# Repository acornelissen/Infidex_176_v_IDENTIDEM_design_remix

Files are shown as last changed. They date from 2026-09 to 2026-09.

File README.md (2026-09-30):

# Infidex 176 V x IDENTIDEM.design Remix

> **This is a remix of someone else's design.** The Infidex 176 V is an open source 3D-printed panoramic 35mm camera by **Denis Aminev (Time to Waste)**. Everything here builds on his work.
>
> - Original project: **[Infidex 176 V on GitHub](https://github.com/max05210238/Infidex_176_V)**
> - Original designer: **[Denis Aminev — Time to Waste on YouTube](https://www.youtube.com/@time_to_waste)**
> - This remix: **[IDENTIDEM.design](https://IDENTIDEM.design)**
>
> Print the original first if you want the camera as Denis designed it. Attribution stays with him; please keep it with any further remix.

## What this remix is

The camera is unchanged where it counts: same 3:1 panoramic frame on 35mm film, same Mamiya TLR taking lens, same overall shape. What changed is how it goes together and how you know where you are on the roll.

| | Original | This remix |
|---|---|---|
| Body | One piece | Reworked, and supplied two ways: in one piece, or as two halves glued together with a light-tight lip and alignment pegs |
| Frame counting | Count as you wind | Sprocket-driven gear train and a numbered counter face, starting at 25 |
| Counter dial | None | Two versions: a free-running dial, or one held by a ball plunger for a steadier reading |
| Rewind knob | Spring detent | Three ball plungers |
| Take-up coupling | Dog coupling | Inner-ratchet with three ball plungers for wind and rewind, magnets optional |
| Spool retention | Glued washer | Printed split collar (`takeup-washer-stopper`) that clicks into the groove |
| Pressure plate | Foam | Printed leaf-spring platen, bonded to the door at both ends |
| Fixings | Glue and press fits | Heat-set inserts and screws throughout |
| Viewfinder | Separate | Cold-shoe viewfinder coupled to the focus helicoid |

## Focusing scale generator

**[infidex176v-focus-scale.identidem.design](https://infidex176v-focus-scale.identidem.design/)** makes a focusing scale for your own lens. Give it the focal length, the helicoid thread lead and your focus ring diameter, and it returns the scale as SVG or Gerber, marked from infinity down to 1.44 m, ready to print as a decal or etch as a plate.

## Specifications

Carried over from the original design:

- **Format:** 3:1 panoramic, 72 × 24 mm on 35mm (135) film
- **Frames:** 18 per 36-exposure roll, or 19 if you load in darkness
- **Lens:** Mamiya TLR taking lens, 80mm or 55mm, from the C2/22/220 or C3/33/330 series
- **Body:** about 168 × 67 × 38 mm
- **Filament:** under 600 g for a camera
- **Tripod mount:** 3/8"-16 thread printed straight into the base, five turns and 8.5 mm deep. Most tripods and quick-release plates are 1/4"-20, so fit a 3/8" to 1/4" bushing and leave it in. Start it by hand: a printed thread strips if you drive it with a tool.

Specific to this remix:

- **Frame counter:** 50:1 spur train, module 0.6, four meshes (12:32, 12:30, 12:30, 12:36), one counter-face turn per 25 frames
- **Counter face:** starts at 25 as the loading position, then reads 1, 2, 3 and on as you wind; friction-fitted under a thumbscrew, reset by loosening it and turning 25 back to the marker
- **Counter dial:** simple (free-running) or drag (one extra ball plunger presses on the dial rim), see [Counter dial: simple or drag](#counter-dial-simple-or-drag)

## Files

| File | What it is |
|---|---|
| `cad/Infidex176V-IDENTIDEM.design-remix.step` | Full assembly, STEP, for any CAD package |
| `cad/Infidex176V-IDENTIDEM.design-remix.f3d` | Fusion source for the camera |
| `cad/Infidex176V-IDENTIDEM.design-remix-counter-train.f3d` | Fusion source for the parametric counter gear train |
| `3mf/Infidex176V-IDENTIDEM.design-remix.3mf` | Print-ready project, all parts laid out across nine plates |
| `3mf/parts/` | One 3MF per part, for reprinting a single part |
| `Infidex-Hardware-Map.pdf` | Hardware placement and assembly guide, 7 pages, built from `docs/hardware-map/` |
| `tools/InfidexCounterTrain/` | Fusion script that rebuilds the counter train from parameters, see [`tools/README.md`](tools/README.md) |
| `flocking/` | Full-size flocking templates, PDF and DXF |
| `docs/` | Section drawings used in this README, and the source of the hardware guide |
| `NOTICE.md` | Denis's redistribution notice, and the remix notice |
| `CHANGELOG.md` | Releases, the commits behind them and which parts to reprint |

## Printing

Print settings follow the original profile and work well in PETG:

- 0.4 mm nozzle, 0.2 mm layer height
- 4 perimeters, up to 25% infill
- Denis printed the original in ABS. PETG works well and is easier to live with
- Both halves of the two-piece body sit flat on their seam face, which puts the largest surface on the bed. Add supports wherever your slicer flags overhangs
- The one-piece body prints as in the original if you would rather not glue

The counter train gears are the finest parts in the model. Print them with the rest of the camera, check the teeth before assembly, and reprint if a tooth is short.

### Parts

Print the whole camera from the project file in `3mf/`, which has everything arranged across 14 plates with the per-part settings already set. `3mf/parts/` holds the same 34 parts one to a file, plus a two-colour version of each counter face and each knob, each in the orientation it is meant to print in and sitting on the bed, for when you only need to reprint one. Updating an earlier build? [`CHANGELOG.md`](CHANGELOG.md) lists the parts to reprint for each release.

Some parts are a choice rather than a set. Print one from each of these:

- **Body:** `body-solid`, or `body-top` and `body-bottom` together
- **Door:** `door-var-1` to `door-var-4`
- **Viewfinder:** `viewfinder-var-1` or `viewfinder-var-2`
- **Focus ring:** `helicoid-focus-ring-ribs` or `helicoid-focus-ring-no-ribs`
- **Helicoid inner ring:** `helicoid-inner-ring-for-80mm-lens` or `helicoid-inner-ring-for-55mm-lens`, to suit your taking lens
- **Counter dial:** `simple-cover` with `simple-counter-face`, or `drag-cover` with `drag-counter-face`. Print them as a matched pair; see [Counter dial: simple or drag](#counter-dial-simple-or-drag) to choose. The project file has all four, the covers on plate 7 and the faces on plate 8, so delete the pair you don't want before slicing
- **Counter face colours:** either face in one colour, or its `-two-colour` file (`simple-counter-face-two-colour`, `drag-counter-face-two-colour`) for markers in a second filament
- **Knob colours:** `advance-knob` and `rewind-knob` in one colour, or their `-two-colour` files for the direction arrows in a second filament. Load each as one object with two parts and give the `-inlay` part the second filament. The arrows are 1.0 mm deep, so the first five layers change colour at 0.2 mm layer height

### Lens mount alternatives

The helicoid in this repo is one of four mounts Denis offers, and the others are worth a look before you commit: **[STL/Lens mount](https://github.com/max05210238/Infidex_176_V/tree/Main/STL/Lens%20mount)** has a classic cone, a tube mount, and an older cone for the T-22 lens alongside the focusing helicoid. The cone and tube install the same way as each other, so swapping is not a big job.

Inside **[STL/Lens mount/Focusing Helicoid](https://github.com/max05210238/Infidex_176_V/tree/Main/STL/Lens%20mount/Focusing%20Helicoid)** there is also a **blue dot set, the `shorter-2mm` files**, which take 2 mm out of the helicoid:

- `Helicoid_FOCUS_ring_ribs_shorter-2mm.stl` or `Helicoid_FOCUS_ring_NO_ribs_shorter-2mm.stl`
- `Helicoid_INNER_ring_80mm_shorter-2mm.stl`

Print the shortened focus ring and inner ring as a pair, not mixed with the full-length ones. The same folder has taller and lower lens boards if your lens will not reach infinity on the standard one.

## Hardware

Everything below was measured from the CAD. [`Infidex-Hardware-Map.pdf`](Infidex-Hardware-Map.pdf) is the same information with section drawings and the exact position of every hole; this README carries the procedure, the PDF carries the coordinates.

### What to buy

| Item | Qty | Where |
|---|---|---|
| M2 × 4 heat-set inserts | 10 | Top cover ×5, cold shoe ×2, counter gear, inner-ratchet, sprocket |
| M3 × 4 heat-set inserts | 4 | Lens standard, front face |
| M2 × 6 countersunk screws | 6 | Top cover ×5, advance knob |
| M2 × 4 countersunk screws | 2 | Cold shoe |
| M3 × 4 cap or countersunk screws | 4 | Lens standard |
| M2 × 6 cap or countersunk screw | 1 | Sprocket gear to sprocket |
| M2 × 4 thumbscrew | 1 | Counter face |
| D2×3 flanged ball plungers | 6, or 7 with the drag cover | Rewind bore ×3, take-up bore ×3, drag cover ×1 |
| Ø5 × 2 magnet | 1 | Inner-ratchet (optional, recommended) |
| Ø4 × 2 magnets | 2 | Take-up spool head (optional, recommended) |
| 3/8" to 1/4" tripod bushing | 1 | Base, in the printed 3/8"-16 socket |

Carried over from Denis's build, not in the printed files, and still needed:

| Item | What for |
|---|---|
| Black flocked self-adhesive paper | Lining the film chambers and the inside of the door to kill reflections and stray light |
| Black light-seal foam | Sealing the door where it closes onto the body |
| Rigid stainless wire, 0.6–0.8 mm | Springs and linkages in the original mechanism |
| Superglue (CA) | Magnets, the pressure plate pads, and the body seam on the two-piece body |

## Assembly

**Read [Denis's assembly guide](https://github.com/max05210238/Infidex_176_V/blob/Main/docs/ASSEMBLY.md) first.** It is the build, start to finish: body, lens mount, film transport, rewind spring and door, finishing parts. What follows here covers only what this remix changes, and assumes you have his guide open beside it.

### Fitting order

1. **All heat-set inserts first** (I1–I11 in the body, I12 in the counter gear, I13 in the inner-ratchet, I14 in the sprocket), before anything else is fitted to those parts. The soldering iron can't then hurt a magnet or loosen a plunger.
2. **Ball plungers** once the body and cover have cooled: P1–P3 in the body's rewind bore, P4–P6 in the cover's take-up bore, and P7 in the tower beside the dial if you printed `drag-cover`.
3. **Magnets** (optional, highly recommended), checking polarity before gluing. M1 goes into the inner-ratchet from below, after I13 is in.
4. **Pressure plate into the door.** Let the glue cure before closing the door on it.
5. **Take-up spool and printed collar:** hold the split collar inside the body under the take-up bore, then lower the spool from the top through it until the collar clicks into the groove.
6. **Two-piece body only:** glue the halves together once their inserts, plungers and magnets are in.
7. **Counter gears** onto their pins in the gear bay, before the top cover goes on.
8. **Screws:** top cover, cold shoe, lens standard, advance knob, then the counter face. With the cover screwed down, turn the sprocket by hand and check the counter train runs freely.
9. **Flocking and foam last,** after a dry run with the back open. The tripod bushing can go in whenever.

### Heat-set inserts

Fourteen in all, every one 4 mm long in a hole 4.0 mm deep: ten M2 × 4 and four M3 × 4. Buy the 4 mm length, not the common 5.7 mm.

- **I1–I5**, M2, top face, for the top cover
- **I6–I7**, M2, top face, for the cold shoe
- **I8–I11**, M3, front face, for the lens standard
- **I12**, M2, counter gear hub
- **I13**, M2, top of the inner-ratchet
- **I14**, M2, top of the sprocket

For PETG, start the insert tip at about 230 °C. Let the insert sink under its own weight with light pressure, keep it square, and stop when it's flush. Face-down on a flat plate while it's still warm is an easy way to square it up. Stand the body on its base for I1–I7 and lay it on its door side for I8–I11.

I14 goes into the top of the sprocket, and the sprocket gear screws down onto it. I13's hole goes right through into the M1 magnet pocket underneath, so press it flush with the top and check from below that no melted plastic has pushed into the magnet pocket.

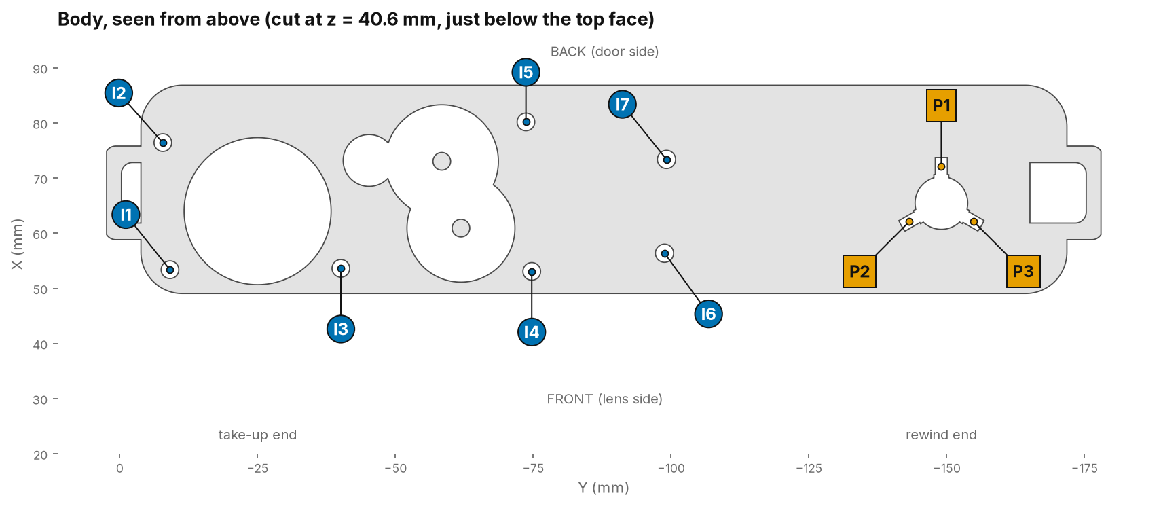
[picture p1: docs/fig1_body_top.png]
Body from above with insert and plunger positions


### Ball plungers

All of them are D2×3 flanged plungers (Ø2 body, Ø2.5 nose flange, 3 mm long overall, Ø1.5 ball standing 0.4 mm proud of the flange, about 5 N) in radial holes. Each of P1–P6 opens into a shaft bore and stops short of the outside wall, so **P1–P6 go in from inside the bore**, flange in its seat flush with the bore wall and ball pointing at the shaft.

P1–P3 sit 120° apart around the body's rewind bore and act on the rewind knob. P4–P6 repeat the pattern in the top cover's take-up bore and ride in the inner-ratchet's W and R detent grooves. Both covers have P4–P6. P7 is only on `drag-cover`: it sits in the tower on the lens side of the dial and presses on the counter face rim, see [Counter dial: simple or drag](#counter-dial-simple-or-drag).

The holes are drawn Ø2.2, 3.1–3.2 mm deep in the body (P1–P3) and 2.6 mm deep in the cover (P4–P6), each behind a Ø2.7 flange seat about 0.6 mm deep. With a 0.4 mm nozzle they print close to Ø2.0, which gives a press fit. Push the plunger body-first from inside the bore with a flat-ended rod until the flange sits in its seat and is level with the bore wall. If one is loose, put a small drop of CA on its body before pressing it in. Keep glue away from the flange and the ball, or the ball will stick.

P7's hole is also Ø2.2, 2.8 mm deep behind a Ø2.7 flange seat, but it prints horizontally, so it may come out slightly oval. The seat is set 0.1 mm deeper than the tower's inner face, so a seated flange stands 0.1 mm proud of the face. The ball pushes the face 0.14 mm across, until its skirt meets the cover step on the far side, and in that position the flange stays 0.1 mm clear of the dial rim. Fit P7 before the counter face goes on, while you can reach the tower's inner face.

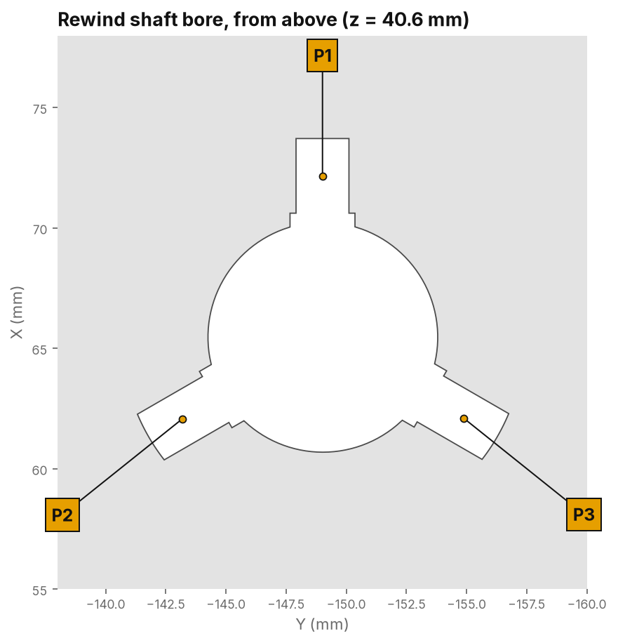
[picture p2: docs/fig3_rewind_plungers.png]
Rewind bore in the body, three plunger holes 120 degrees apart


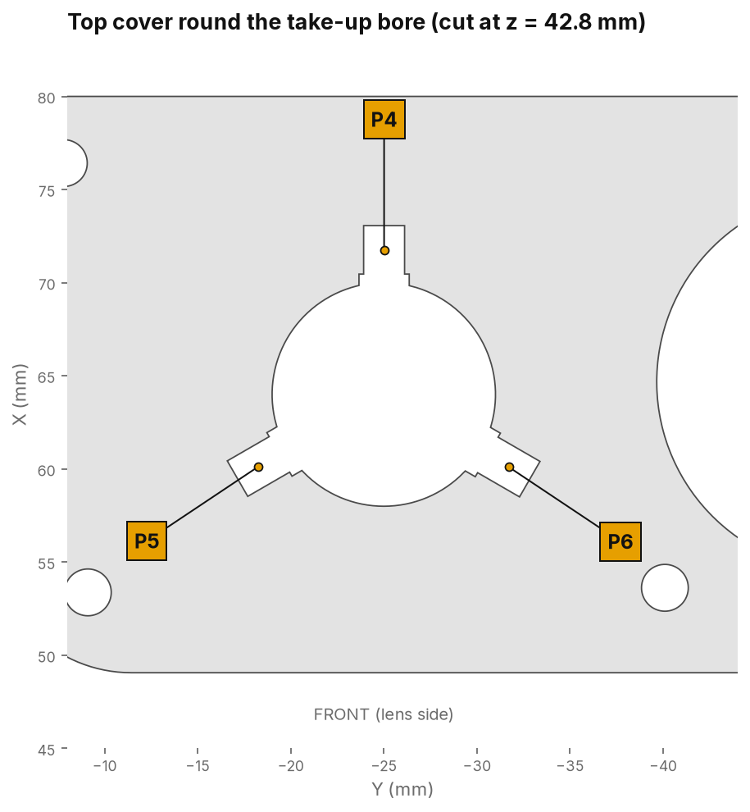
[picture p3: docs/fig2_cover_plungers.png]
Take-up bore in the top cover, the same pattern in the cover


### Magnets

Optional, but highly recommended. The camera works without them; they hold the inner-ratchet firmly down on the spool head. All three sit on the take-up axis, and when the camera is assembled the Ø5×2 faces the Ø4×2 stack across a gap of about 0.3 mm.

| Ref | Magnet | Pocket | Fits from |
|---|---|---|---|
| M1 | Ø5 × 2 | Ø5.1 × 2.1 | Underside of the inner-ratchet, pressed to the pocket floor |
| M2 | Ø4 × 2 | Ø4.1 × 4.2 | Top of the spool head, at the bottom of the pocket |
| M3 | Ø4 × 2 | same pocket | On top of M2, 0.2 mm below the top of the head |

**Polarity.** The top face of the M2/M3 stack has to *attract* the exposed face of M1. Let M2 and M3 snap together into a stack first. Then touch M1 to the top of the stack and mark M1's exposed face with a pen dot before separating them. Glue M1 with the dot facing out of its pocket and the stack with its free face up, then check the attraction with the parts dry-fitted before the glue cures.

### Screws

Each length is the longest standard screw that stays inside its insert without bottoming out, worked out from the head seat, the clamped part and the depth of the hole below.

| Ref | Screw | Qty | Holds | Into | Room below the tip | Thread in insert |
|---|---|---|---|---|---|---|
| S1–S5 | M2×6 countersunk (ISO 10642) | 5 | Top cover to body | I1–I5 | 0.2 mm | 3.8 mm |
| S6–S7 | M2×4 countersunk (ISO 10642) | 2 | Cold shoe to body | I6–I7 | 1.3 mm | 2.7 mm |
| S8–S11 | M3×4 socket cap (ISO 4762) or countersunk | 4 | Lens standard to body | I8–I11 | 1.5 mm | 2.5 mm |
| S12 | M2×6 countersunk (ISO 10642) | 1 | Advance knob to inner-ratchet | I13 | 1.65 mm to M1 | 2.35 mm |
| S13 | M2×4 thumbscrew, flat underside | 1 | Counter face to counter gear | I12 | 0.9 mm | 3.1 mm |
| S14 | M2×6 socket cap (ISO 4762) or countersunk | 1 | Sprocket gear to sprocket | I14 | 0.25 mm | 4.0 mm |

The cold shoe (M2×4) and lens standard (M3×4) lengths are proven on the printed camera and leave plenty of clearance. The M2×6 cover and sprocket screws are the longest that fit: the next size up bottoms out. The S1–S5 figures are with the cover screwed down, which seats it 0.1 mm below its drawn height. S14 takes the full depth of its insert whether it is a cap or countersunk screw, so run it down gently and stop when it seats. Don't go longer on S12 either, as an M2×8 would reach 0.35 mm into the M1 magnet pocket.

On heads: the knob's seat for S12 is a Ø3.7 × 90° countersink 0.75 mm deep, so a standard M2 flat head (Ø3.8) finishes level with the knob face. The countersinks in the cover and cold shoe are Ø3.7–3.8 at 90°, so M2 flat heads finish flush or a hair proud. The lens-standard counterbores are Ø7.3 × 3.1 deep, so either an M3 cap head (Ø5.5 × 3) or an M3 countersunk head sits below the surface.

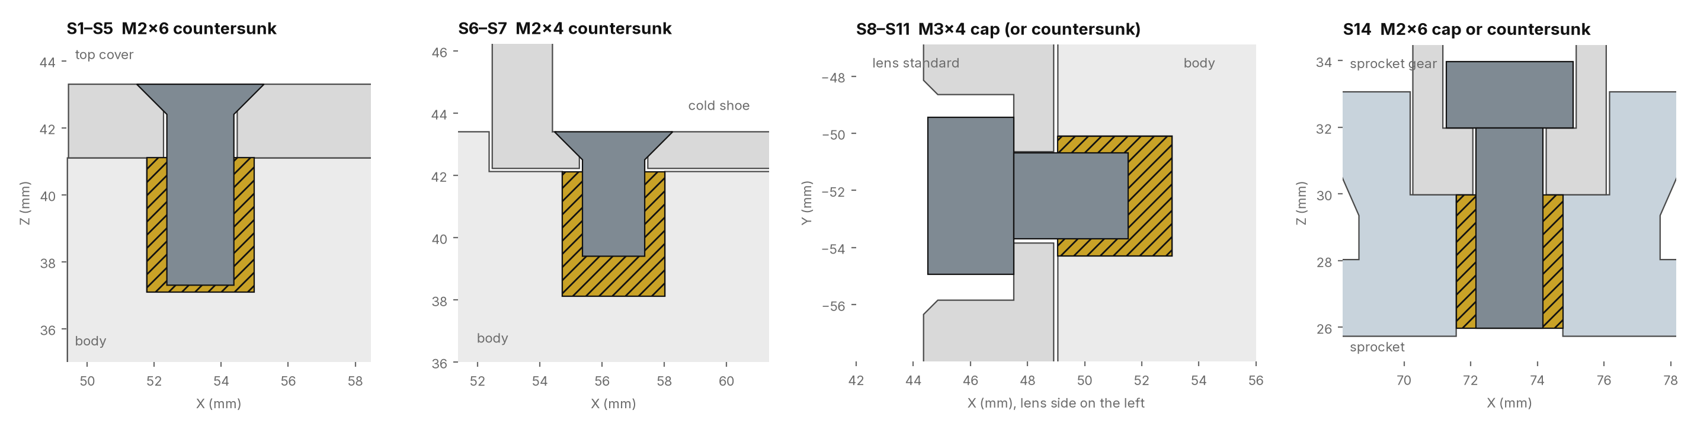
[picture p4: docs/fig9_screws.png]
Screws seated in their inserts


### Counter train

The four counter gears drop onto printed pins in the body. From the sprocket: idler 1 is `counter-coupling-gear`, idler 2 is `counter-idler-1`, idler 3 is `counter-idler-2`, and the dial wheel is `counter-gear`. The idler bores are 0.2 mm over their pins: Ø3.4 on the Ø3.2 pins, and Ø4.2 over the Ø4.0 foot of the stepped pin under idler 1. If an idler won't drop on or turns stiffly, run a drill of the bore size through it by hand rather than sanding the pin: 3.4 mm, or 4.2 mm for the lower part of idler 1's stepped bore. The idler 1 and 2 pins run up to the top of their gears so they cannot tilt out of mesh, and the idler 3 pin stops level with the body's top face, which is the face the two-piece top half prints on. The top cover sits on the floor of its recess once it is screwed down, and every gear keeps at least 0.3 mm of end float in that position. A 25 mm boss on the body around the dial locates the cover in a 25.2 mm recess, so the cover sits concentric with the dial. The dial wheel is centred on the counter face by its hub, and the face turns in the cover on a close-running step.

Before fitting the counter face, screw the cover down and turn the sprocket by hand. The train should run freely with no tight spots. If it only binds with the cover on, look for sagged bridging on the cover's pocket ceilings and clean it up rather than backing the screws off.

### Counter face

The face starts at 25 and counts up: 25 is the loading position, then winding on takes you to 1, 2, 3 and so on. There is no zero. Lay the face on the hub with 25 against the marker and finger-tighten S13. The marker is the triangle recessed into the cover beside the dial, in the same place on both covers. The face grips on friction, so to reset it for a new roll you loosen the thumbscrew, turn 25 back to the marker, and tighten again. Don't use thread lock. The head sits in a Ø6.0 × 0.5 mm recess, so a head up to about Ø5.8 sits down in the face.

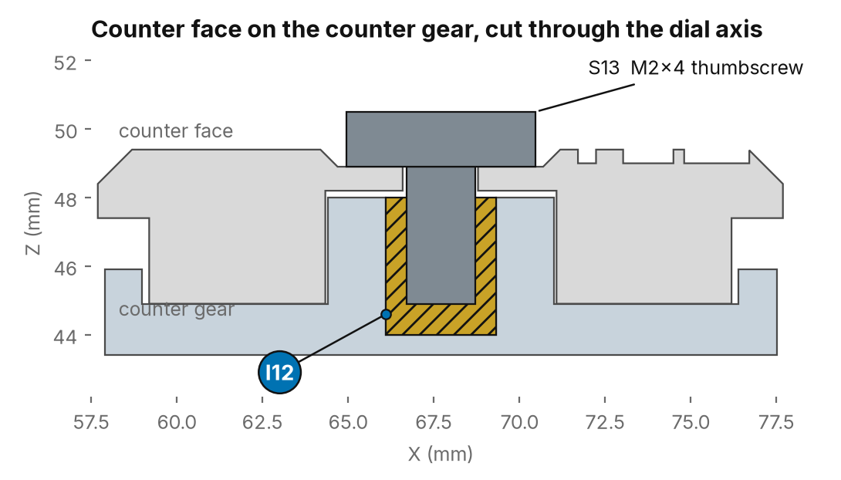
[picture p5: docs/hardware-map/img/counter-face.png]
Counter face on the counter gear, in section


Every frame has its own marker on the rim, 0.9 × 1.7 mm and 0.4 mm deep, with a wider one beside each number, so you can see at a glance when a frame lines up with the marker. Print the face dial-down. In one colour the recesses read on their own, and a little paint or wax crayon wiped across them makes them stand out further. For two colours, open `3mf/parts/simple-counter-face-two-colour.3mf` or `3mf/parts/drag-counter-face-two-colour.3mf`, load it as one object with two parts, and give `counter-face-inlay` the second filament. The inlay is the same for both faces. Only the first two layers change colour.

### Take-up spool and collar

C1 is a printed part, not a bought one, named `takeup-washer-stopper` in the files. It is a split ring (Ø9.5 bore × Ø13.0 × 1.7 mm) that stops the take-up spool lifting out of the body, sitting in the groove just below the spool head (Ø9.3 at the root), directly under the body's take-up bore. The collar is wider than the bore, so once it's in, the spool can't pull up through the top.

1. Open the body and hold the collar inside it, directly under the take-up bore, with the split facing the lens side.
2. Lower the take-up spool into the body from the top. As it comes down, its bottom end passes through the collar, and the split lets the collar open over the Ø10.8 barrel.
3. Keep lowering the spool until the collar snaps closed in the groove below the head, then spin the spool to check it turns freely without lifting.

The advance knob screws down into the inner-ratchet, which sits over the spool head. The optional magnets hold the two together, and the collar under the take-up bore stops the spool lifting.

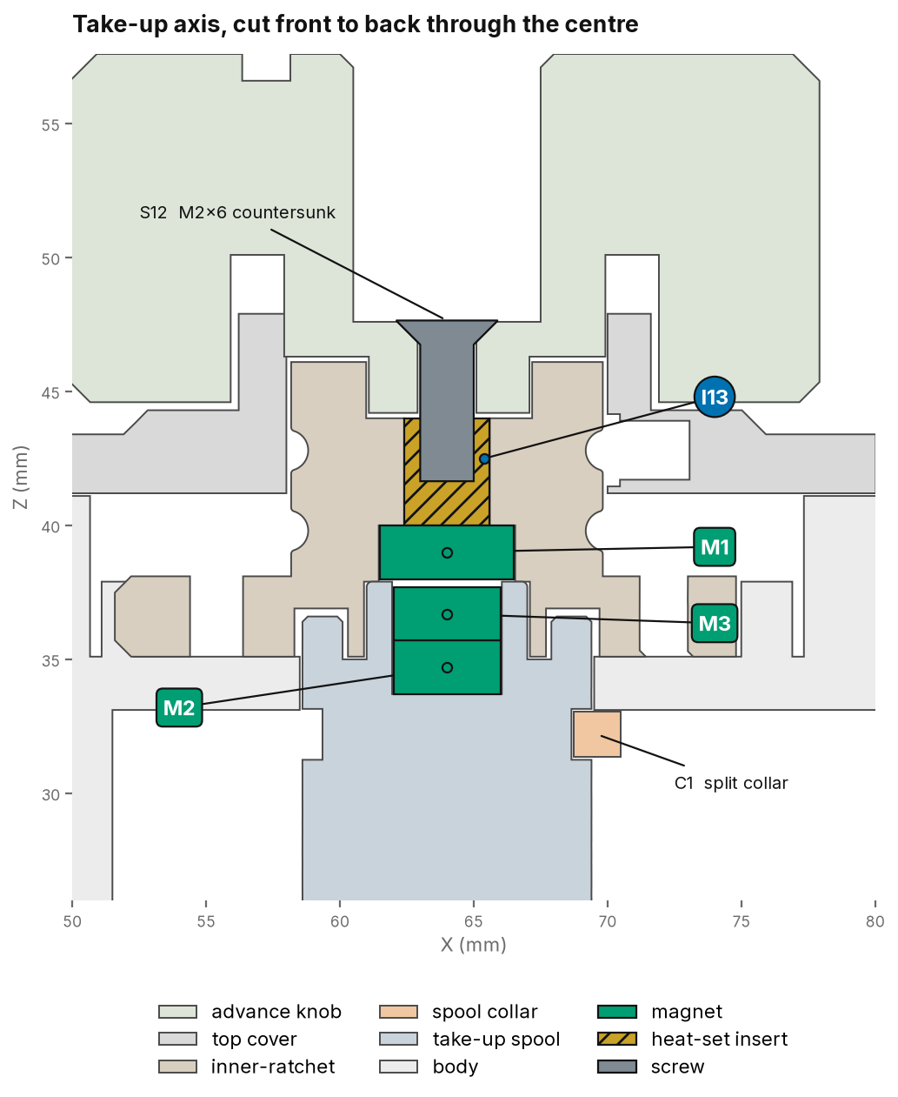
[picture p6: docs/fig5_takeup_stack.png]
Section through the take-up axis


### Pressure plate

G1 is one printed part: a rigid platen on a single thin leaf. The leaf joins the platen in the middle and has a bond pad at each end. **Glue only the two end pads to the door**, never the platen or the middle of the leaf. The door's inside face has a shallow 0.2 mm recess (83.6 × 33.5 mm) that locates the plate, leaving about 1 mm spare at each end and 0.25 mm top and bottom.

Clean both surfaces with IPA. Put a thin line of CA or a strip of thin double-sided tape on each end pad only. Seat the plate square in the recess with the platen facing the film, and press on the pads alone for 30 seconds. Keep glue out of the gap under the leaf, or the plate stops flexing.

With the door open, the leaf holds the platen 1.6 mm proud of its working position. Closing the door on loaded film pushes the platen back onto the film rails and flexes the leaf by about 0.8 mm, which gives the pressure on the film. Don't shim or glue anything under the leaf to take up that gap.

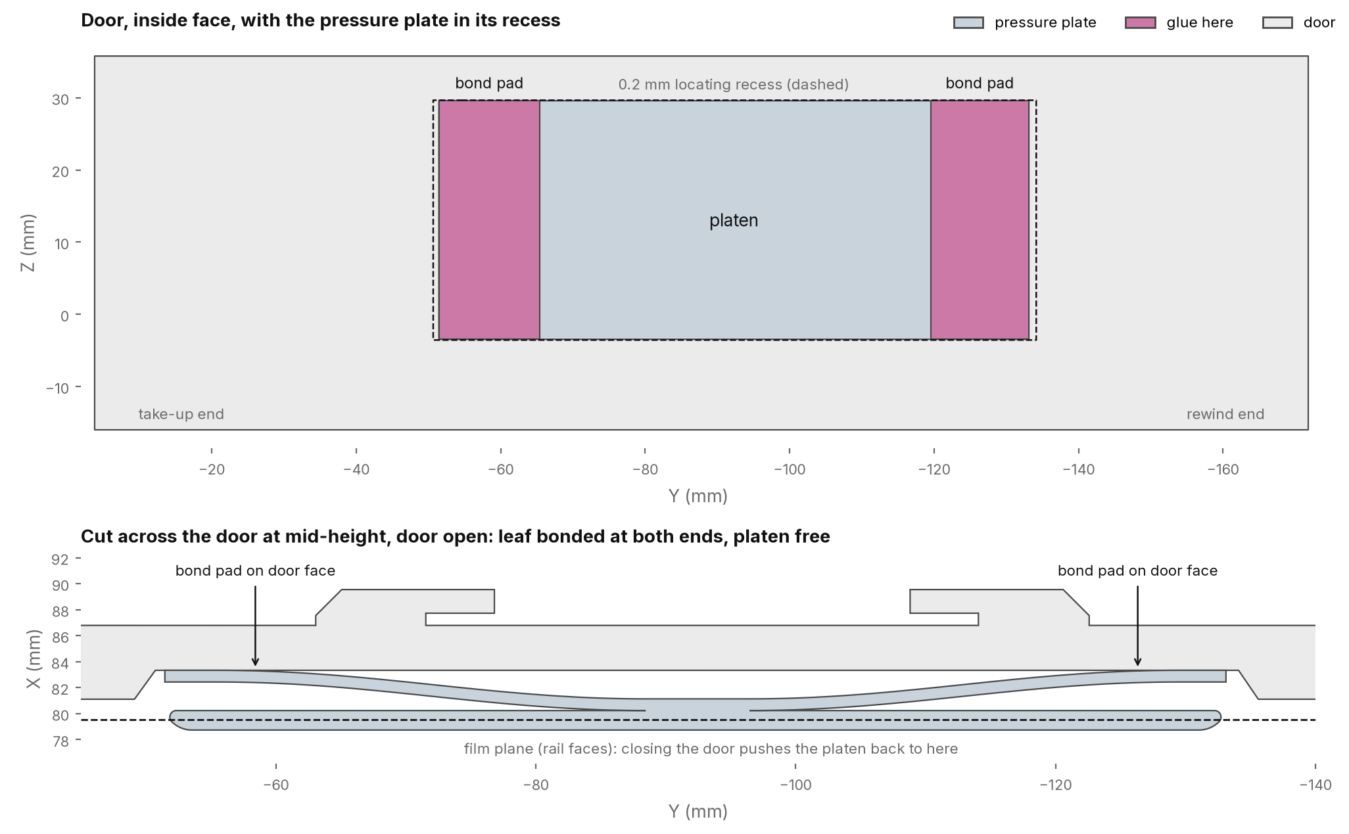
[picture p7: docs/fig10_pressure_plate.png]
Pressure plate in the door


### Two-piece body seam

Skip this if you printed the one-piece body. The two halves meet on a flat seam about 34 mm above the base. A 2 mm ridge on the bottom half runs right around the film chambers and the film path; the top half has the matching groove. Light arriving along the glue line has to climb over that step to reach the film, which is why only the chambers and the path are ridged and the rest of the seam is plain.

Four alignment pegs set the halves: Ø3.8 × 2 mm posts inside the top half's groove, dropping into Ø4 mm holes in the ridge. Dry-fit before any glue. The halves should sit down with no rock and no light gap at the seam; if they rock, the ridge is not seating and the groove needs a clean-up rather than more clamp.

Fit every insert, plunger and magnet first, while the halves are still separate and easy to hold. Then run a thin bead of CA or epoxy on the flat land outside the ridge, press the halves together on the pegs, and clamp lightly until it cures. Keep glue off the ridge crest and out of the groove, or the halves will stand proud and leave the gap you were trying to close.

### Tripod socket

The socket is printed, not an insert: a 3/8"-16 thread moulded straight into the base on the centreline, five turns and 8.5 mm deep. Nothing is pressed or glued into it. Most tripods and quick-release plates are 1/4"-20, so fit a 3/8" to 1/4" bushing and leave it in.

Start the bushing by hand and stop as soon as it seats. A printed thread strips if you drive it with a tool, and a 1/4" screw run straight into the 3/8" hole will tear it out. If the thread is tight from the print, run the bushing in and out a couple of times to clear it rather than cutting it.

### Flocking templates

The remix chamber is a different size from the original, so the templates in Denis's guide won't fit. [`flocking/flocking-templates.pdf`](flocking/flocking-templates.pdf) has every piece at full size on one A4 page. Print it at 100% and check the 50 mm bar before cutting. The same outlines are in [`flocking/dxf/`](flocking/dxf) for a cutting machine, one file per piece plus `all-pieces.dxf` with both sides laid out.

| Piece | Qty | Size (mm) | Where |
|---|---|---|---|
| S | 2 | 20.78 × 39.20 | Left and right chamber walls |
| T | 1 | 70.60 × 23.53 | Ceiling, tab towards the lens |
| B | 1 | 70.60 × 23.28 | Floor, tab towards the lens |
| R1 | 1 | 70.60 × 9.10 | Rear wall below the film gate (optional) |
| R2 | 1 | 70.60 × 4.75 | Rear wall above the film gate (optional) |
| P | 1 | 77.08 × 32.63 | Pressure plate, on the platen's film face |

The chamber is 72.0 mm wide, 39.6 mm high and 21.2 mm deep at the corners, with a 58.5 mm recess at the front centre that the tabs on T and B reach into. The pieces allow for 0.5 mm flocked paper and 0.2 mm clearance per edge, so fit them in the order above: the sides first, then T and B between them, then R1 and R2. Leave the film gate opening and its throat bare, or the paper will crop the frame. Both bodies have the same chamber, and on the two-piece body the side pieces also cover the seam.

P covers the film face of the pressure plate platen (77.48 × 33.03 mm), leaving 0.2 mm of platen showing all round so no edge overhangs to catch the film. Stick it on before the plate goes into the door, and press it flat so the edges don't lift.

### Light seals and wire

Flocking and foam go in last, after everything else is fitted and the camera has been dry-run with the back open. They are the one thing you cannot fit around.

## Body: one piece or two

Both bodies are remixed parts, not the original. The one-piece body carries all the changes above and needs no gluing. The two-piece body is the same part split horizontally through the middle, which suits a smaller printer and puts both halves flat on the bed, seam face down. See [Two-piece body seam](#two-piece-body-seam) for how the halves go together. The hardware is the same either way.

## Counter dial: simple or drag

The counter comes two ways. Pick one pair and print both parts of it; the covers and faces are otherwise identical, take the same screws, inserts and gears, and fit the same body.

| | Simple | Drag |
|---|---|---|
| Parts | `simple-cover`, `simple-counter-face` | `drag-cover`, `drag-counter-face` |
| Extra hardware | None | One more D2×3 ball plunger (P7) |
| How the dial moves | Turns only with the gear train; its rim rests on the cover under its own weight | A ball plunger in a tower beside the dial presses on the face's plain rim, with a detent flute under every frame. The tower itself stays 0.2 mm clear of the rim |
| Marker for 25 | Triangle recessed into the cover | The same triangle, exactly five frames round from P7 |
| Height | Face is the highest point (Z 49.4 in the CAD) | Tower stands 1 mm above the face (Z 50.4) |

**Choose simple** if you want the fewest parts and the lightest wind. The dial is driven only by the gears, so it adds nothing to the effort of winding on, and there is one less plunger to fit. The trade-off is that the four meshes each have a little backlash, so the face can rock a fraction of a frame either way and does not always come to rest in exactly the same place.

**Choose drag** if you want the dial to read the same every time. The plunger's light, constant friction keeps the backlash taken up in one direction, so the face stops where the gears leave it and doesn't flutter when the camera is knocked or carried. A V-flute across the rim under each frame marker gives the ball a seat and a firm click, so the face settles with the number centred on the triangle. The costs are one more plunger, a slightly heavier wind, and the tower standing proud of the dial.

With the drag option, the thumbscrew has to hold the face against the plunger's friction and the pull of each flute as well as the gears. Tighten S13 firmly by hand, then wind through a few frames and check that the face stays with the train rather than slipping on the hub. If it slips, tighten S13 a little more rather than backing off the plunger. Set the face for a new roll as in [Counter face](#counter-face); with 25 on the marker, a flute sits under the ball and the face clicks into it. Print the pair together: the simple face has no flutes, so on the drag cover it drags without clicking, and the drag face needs the drag cover's tower, which sits 0.14 mm nearer the dial than the 2.1.0 one.

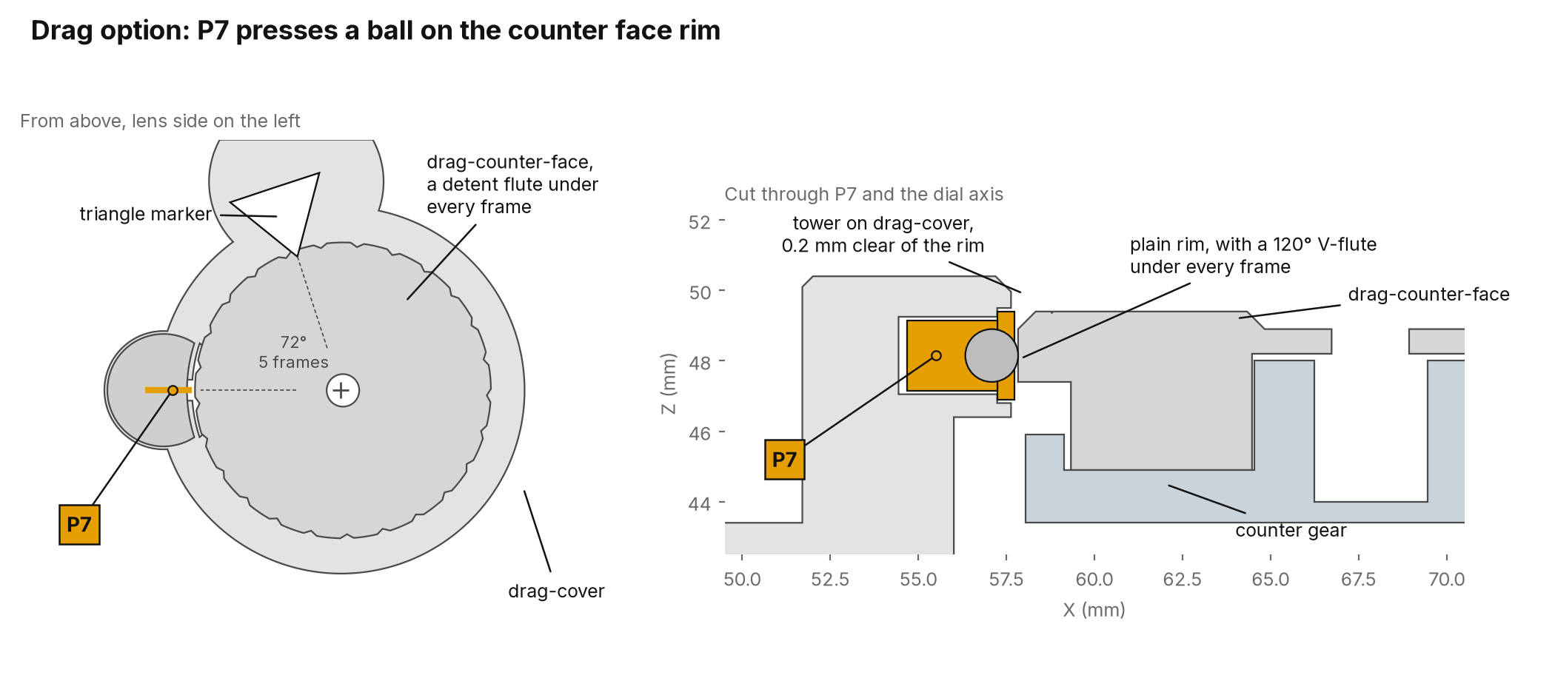
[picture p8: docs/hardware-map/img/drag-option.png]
Drag option, from above and cut through P7


## Parametric counter train

`cad/Infidex176V-IDENTIDEM.design-remix-counter-train.f3d` holds the counter gear train as a parametric model, so you can change it without redrawing the gears. The sprocket and dial axes stay fixed where the body needs them; the three idler axes follow from the centre distances. Module, tooth counts, profile shift, backlash, the height of every gear face and the stepped bores are all parameters, and the defaults rebuild the idlers exactly as the main model has them, so a different reduction or a coarser module is a table edit and a rebuild. The sprocket pinion and the dial wheel come out as tooth zones only: `counter-gear`'s hub and face recess belong to the main model, so keep them when you swap in new teeth.

Start from the values in the file if you are only nudging it: the train is 50:1 in four meshes and the gears are already near the limit of what a 0.4 mm nozzle resolves.

`tools/InfidexCounterTrain/` is a Fusion script that builds the same train from a table of `ct_*` user parameters, so you can change module, tooth counts, backlash or the idler positions and rerun it rather than redrawing the gears. It refuses to build a layout that cannot close, that would clash with the sprocket hub or the dial disc, or that would stack two gears too close. The gear maths sits in plain Python next to it with tests you can run outside Fusion. See [`tools/README.md`](tools/README.md).

## Credits and licence

Original design by **Denis Aminev (Time to Waste)**: [YouTube](https://www.youtube.com/@time_to_waste) · [Infidex 176 V repository](https://github.com/max05210238/Infidex_176_V).

There is no formal licence on either the original or this remix. Denis gave permission to redistribute the project files on any platform, with attribution to him kept intact, and the same terms apply here: use it, print it, sell prints of it, fork it, but keep the credit and keep [`NOTICE.md`](NOTICE.md) with it.

Remix, hardware guide and drawings by [IDENTIDEM.design](https://IDENTIDEM.design).

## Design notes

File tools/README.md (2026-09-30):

# Counter train rebuild script

A Fusion script that builds the frame-counter gear train from a table of parameters, so a different reduction or module is a value edit and a rerun rather than a redraw.

## What is in here

| Path | What it is |
|---|---|
| `InfidexCounterTrain/InfidexCounterTrain.py` | The Fusion script: reads the parameters, validates the layout, draws and extrudes the gears |
| `InfidexCounterTrain/gearcalc.py` | The gear maths: ratios, centre distances, the solved idler axes, tooth profiles, clash checks. No Fusion imports |
| `InfidexCounterTrain/params.py` | The parameter table and its defaults |
| `test_gearcalc.py`, `test_params.py` | Tests, run outside Fusion |

## Install

1. In Fusion, press Shift+S to open Scripts and Add-Ins.
2. Click the **+** next to the script list, choose **Script or add-in from device**, and pick the `InfidexCounterTrain` folder from this repository.

Nothing needs installing into Fusion's Python. The script uses only the Fusion API and the two modules beside it.

## Use

1. Make a new **Hybrid Design** or **Assembly Design** document. Part Design only allows one component, so the script falls back to plain bodies there.
2. Run **InfidexCounterTrain**. The first run creates the `ct_*` user parameters with the values of the train in this repository and builds the gears. It also removes `ct_*` parameters left by older versions of the script.
3. Edit any value in **Modify > Change Parameters**, then run the script again. Fusion cannot drive involute tooth curves from parameters on its own, so a rerun is what rebuilds them. Each rebuild replaces the previous one as a single timeline group.

## Parameters

| Parameter | What it sets |
|---|---|
| `ct_module`, `ct_pressure_angle` | Gear module and pressure angle |
| `ct_pinion0..3_teeth`, `ct_wheel1..4_teeth` | Tooth counts, sprocket end to dial end. Pinion *n* drives wheel *n + 1* |
| `ct_thinning` | Tooth thinning per gear, which is the backlash share |
| `ct_pinion_shift` | Profile shift on the pinions; the wheels take the opposite |
| `ct_pinion_tip_reduction`, `ct_wheel_tip_reduction` | Tip shaves |
| `ct_sprocket_x/y`, `ct_dial_x/y` | The two fixed axes in the body |
| `ct_idler1_angle`, `ct_idler2_angle`, `ct_idler3_elbow` | Where the idlers sit |
| `ct_pinion0_z0/z1`, `ct_wheel1..4_z0/z1`, `ct_pinion1..3_z1` | Underside and top of every toothed layer; each idler pinion starts on top of its wheel |
| `ct_bore1..4`, `ct_bore1..4_upper`, `ct_bore1..4_step_z` | Bore below and above a step, and the step height; set both diameters equal for a plain bore |
| `ct_pinion_phase` | Tooth angle of the pinions; each wheel is turned to mesh with the pinion driving it |
| `ct_clearance` | Minimum radial gap to non-meshing parts |
| `ct_axial_clearance` | Minimum gap between gears that pass over each other |

Axis numbers and the part files they print as: idler 1 is `counter-coupling-gear`, idler 2 is `counter-idler-1`, idler 3 is `counter-idler-2` and the dial wheel is `counter-gear`. The built components carry both names.

The three idlers come out whole. The sprocket pinion and the dial wheel come out as tool bodies: only their tooth zones, which you swap into the sprocket and `counter-gear` in the main model. Everything else on `counter-gear` is drawn there and not by this script: the hub, the insert hole and the recess the face sits in. So when you bring in new dial-wheel teeth, replace only the toothed ring and keep those features. `mise run clearance` then shows whether the faces still sit on the gear.

### 20-frame train

Set `ct_pinion1_teeth` to 14 and `ct_wheel2_teeth` to 28, then rerun. Mesh 2 keeps its 12.6 mm centres, so every axis stays where it is and only idler 1 and idler 2 change. Don't put the 14:28 on mesh 3 instead: the same ratio works there, but a 14-tooth pinion on idler 2 cuts 0.33 mm into both covers. The script can't see the covers, so run `mise run clearance` on any new train. The train drops from 50:1 to 40:1, and the dial turns once per 20 frames instead of 25. The summary shows the frames per dial turn after every build.

The sprocket and dial axes stay put; idler 3 is solved so it meshes with both idler 2 and the dial wheel. If a set of values cannot close, a gear would come within `ct_clearance` of the sprocket hub or the dial disc, or two stacked gears would come within `ct_axial_clearance` of each other, the script stops with a message instead of building. It does not know about the body walls or the cover bosses, so look at the gear bay yourself after a big change.

## Tests

`gearcalc.py` and `params.py` have no Fusion imports, so they can be tested outside Fusion. From the repository root, with [mise](https://mise.jdx.dev):

```sh
mise run test
```

The tests cover the ratio and frames per dial turn, centre distances, the solved axis positions, radial and axial clash detection, the face heights and stepped bores of the built gears, the wall left under the pinion teeth, the tooth phases the model is drawn at, tooth geometry, the contact ratio of every mesh (at least 1.3 as drawn, and still 1.0 with the axes 0.2 mm apart), that meshing outlines do not overlap through a full pitch, and the same checks on the 20-frame train.

## CAD export and checks

`cad/` is a small Python package that keeps the 3MFs in step with the STEP (`cad/Infidex176V-IDENTIDEM.design-remix.step` at the repository root). Run it through mise from anywhere in the repository:

| Task | What it does |
|---|---|
| `mise run verify` | Checks every file in `3mf/parts/` and every object in the Bambu project. Each mesh must be closed, consistently wound and of positive volume; each part file must match the STEP solid of the same name within 0.02 mm RMS and 0.5 % volume; the inlay in a two-colour file must sit where the STEP puts it; each project object must match its part file. Every plate is checked too: each object inside its bed, clear of the bed's excluded corner, resting at z 0, and at least 6 mm from the other objects on the plate. Prints a table and exits non-zero on any failure. Add part names to check only those. Takes about two minutes |
| `mise run export -- <part names>` | Re-exports parts after a CAD change. For every mesh of the part (its part file, a two-colour file holding it, its project object) it fits the solid from the STEP as committed (`--ref`, default `HEAD`) onto the mesh, then writes the solid from the current STEP through the same transform, so each copy keeps its place on the bed. A part whose shape is unchanged is placed by its own fit instead, so moving it in the assembly doesn't move it on the bed. Everything else in the archives is copied byte for byte. If the old solid does not fit a mesh within 0.02 mm, nothing is written. Safe to run twice before committing: a mesh the current solid already fits better, within 0.001 mm, is reported as already exported and left alone. `--dry-run` reports without writing |
| `mise run add -- <solid> --like <sibling>` | Adds a solid that is new in the STEP, printed like a sibling part (`--like simple-counter-face` for a new face). Writes `3mf/parts/<solid>.3mf` in the sibling's layout, through the transform that fits the sibling's solid onto the sibling's mesh, so orientation and bed contact match. If the sibling has a two-colour file, give `--inlay <STEP solid>` and a `<solid>-two-colour.3mf` is written with the face, the inlay and the group (`--inlay counter-face-inlay` means the loose `Body1`, `Body2`, ... bodies; any other inlay is one STEP solid whose name ends in `-inlay`). In the project, the sibling's object is cloned (print settings, assembly place) and put at a free spot at least 6 mm from everything on the sibling's plate, or on `--plate <number or name>`. Nothing is written if a fit fails, the new part would not rest on the bed like the sibling, or the plate has no room. `--dry-run` reports without writing |
| `mise run add -- <inlay> --inlay-for <part>` | Gives a part already in the 3MFs a second colour. `<inlay>` is a new STEP solid named `<part>-inlay` that fills a recess in the part flush. Writes `3mf/parts/<part>-two-colour.3mf` in the same layout as the counter faces' two-colour files: the part's mesh as it is in its part file, the inlay placed where the STEP puts it relative to the part, and the group. The project is left alone. Nothing is written if the part file is missing, the two-colour file already exists, or the inlay would sit below the bed. `--dry-run` reports without writing |
| `mise run plates -- list` | Lists the project's plates and their objects. `add-plate <name>` appends an empty plate, `rename-plate <plate> <name>` renames one, `move <object> <plate>` moves an object to a free spot on a plate. A plate is given by number or name |
| `mise run layout` | Gives each counter option its own plate: simple cover, drag cover, 25-frame idlers, simple and drag 25-frame faces. The shared counter gears stay on Small parts 2. Safe to rerun: existing plates are reused by name and parts already in place are left alone. A new option is a line in `LAYOUT` in `cad/layout.py`, once `add` has put its parts in the project |
| `mise run clearance` | Checks the counter train against the housings and each other, as assembled in the STEP. Reports the shared volume and the smallest gap per pair, and fails on an overlap over 0.001 mm³. Alternatives, of which a camera has one, are never checked against each other: the covers (`simple-cover`, `drag-cover`), the idler sets (today only `counter-idler-1` with `counter-idler-2`) and the counter faces (`simple-counter-face`, `drag-counter-face`). A new option is an entry in `COVERS`, `IDLER_SETS` or `FACES` in `cad/clearance.py`. Each idler set is checked in its own train (`ratchet-coupling-gear`, `counter-coupling-gear`, idler 1, idler 2, `counter-gear`) and against `body-solid`, `body-top` and each cover; each face against each cover and `counter-gear`, which holds it. Meshing pairs, where a pinion drives the next wheel in the train, are reported but not judged; their teeth are the gear maths' job. Options not in the STEP yet are skipped with a note |

Workflow after changing the CAD: export the STEP from Fusion over the one in `cad/`, run `mise run export -- <changed parts>`, then `mise run verify` and, for the counter train, `mise run clearance`. Commit the STEP and the 3MFs together, so the next export fits against the right STEP.

Workflow for a part that is new in the STEP: `mise run add -- <solid> --like <sibling>`, then `mise run verify`. If it is a new counter option, add it to `LAYOUT` and the clearance option sets and run `mise run layout` and `mise run clearance`. Then open the project in Bambu Studio, look over the plates and save it, which redraws the plate thumbnails.

Notes:

- The fit error is measured from the mesh's vertices to the STEP surface, because the vertices of an exported mesh lie on the true surface whatever the facet size. Nearly symmetric parts may come out turned about their own axis by a symmetry step; their footprint on the bed is the same.
- Part file names map to STEP solid names one to one, except `pressure-plate-1` (`pressure-plate (1)`) and the two-colour files, which hold the face and an inlay named after its STEP solid (`counter-face-inlay` stands for the STEP bodies `Body1`, `Body2`, and so on).
- `--step FILE` makes `verify`, `export`, `add` and `clearance` use another STEP, for example one taken from git. `verify` and `add` also take `--parts DIR` and `--project FILE`, to work on copies.
- Plates: Bambu Studio lays plates out in a grid with a stride of the bed size plus a fifth (307.2 mm for the 256 mm bed), and picks the column count from the plate count: the square root, rounded, plus one if the root is above its rounding (`compute_colum_count` in BambuStudio `src/slic3r/GUI/PartPlate.hpp`). It gives each object to the plate it sits on when it loads a project, so when adding a plate changes the column count (at 10 and 17 plates, for example), `plates` and `layout` move every object with its plate. New plates have no thumbnails until Bambu Studio saves the project.

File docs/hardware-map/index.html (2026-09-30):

IDENTIDEM.design Hardware placement guide

Hardware placement guide

# Infidex 176 V x IDENTIDEM.design Remix

Where every heat-set insert, screw, ball plunger, magnet and bonded part goes.

Camera: Infidex 176 V (https://github.com/max05210238/Infidex_176_V), an open source project by Denis Aminev (Time to Waste) (https://www.youtube.com/@time_to_waste). Remix by IDENTIDEM.design.

Every location and screw length below was measured from the remix CAD assembly. Reference codes match the drawings. The remixed body comes two ways, in one piece or as two glued halves, and the hardware is the same for both. Positions are in the CAD assembly frame in millimetres: X runs front (lens) to back (door), Y runs from the take-up end (0) towards the rewind end (−178), Z is up.

I

10 × M2×4 · 4 × M3×4

Heat-set inserts, I1–I14

S

14 screws

6 × M2×6 CSK · 2 × M2×4 CSK · 4 × M3×4 cap or CSK · 1 × M2×6 cap or CSK · 1 × M2×4 thumbscrew

P

6 × D2×3, 7 with the drag cover

Flanged ball plungers, P1–P6, plus P7 on drag-cover

M

1 × Ø5×2 · 2 × Ø4×2

Magnets, M1–M3 · optional, highly recommended

C

Split collar

Take-up spool retainer, C1 · printed part, takeup-washer-stopper

G

Pressure plate

Glued into the door, G1

T

3/8" to 1/4" bush

Tripod adapter, T1 · the socket is printed 3/8"-16

O

Seals and wire

Flocked paper, foam, 0.6–0.8 mm stainless wire · from the original build

## Fitting order

1. All heat-set inserts first (I1–I11 in the body, I12 in the counter gear, I13 in the inner-ratchet, I14 in the sprocket), before anything else is fitted to those parts. The soldering iron can't then hurt a magnet or loosen a plunger.
2. Ball plungers once the body and cover have cooled: P1–P3 in the body's rewind bore, P4–P6 in the cover's take-up bore, and P7 in the tower beside the dial if you printed drag-cover.
3. Magnets (optional, highly recommended), checking polarity before gluing. M1 goes into the inner-ratchet from below, after I13 is in.
4. Pressure plate into the door. Let the glue cure before closing the door on it.
5. Take-up spool and printed collar (takeup-washer-stopper in the files): hold the split collar inside the body under the take-up bore, then lower the spool from the top through it until the collar clicks into the groove.
6. Two-piece body only: glue the halves together once their inserts, plungers and magnets are in.
7. Counter gears onto their pins in the gear bay, before the top cover goes on.
8. Screws: top cover, cold shoe, lens standard, advance knob, then the counter face. With the cover screwed down, turn the sprocket by hand and check the counter train runs freely.
9. Flocking and foam last, after a dry run with the back open. The tripod bushing can go in whenever.

## IHeat-set inserts

Eleven inserts go into the body: seven M2 in the top face (five for the top cover, two for the cold shoe) and four M3 in the front face for the lens standard. Three more M2 inserts go into moving parts: I12 in the counter gear hub, I13 in the top of the inner-ratchet and I14 in the top of the sprocket. Use 4 mm long inserts everywhere. Every hole is 4.0 mm deep. Buy: Amazon ↗ (https://www.amazon.co.uk/s?k=M2+x+4+heat+set+insert+brass) (M2×4), Amazon ↗ (https://www.amazon.co.uk/s?k=M3+x+4+heat+set+insert+brass) (M3×4, not the common 5.7 mm length).

Body from above with insert and plunger positions

Figure 1 · Body seen from above, lens side at the bottom. I1–I7 are pressed in from the top face.

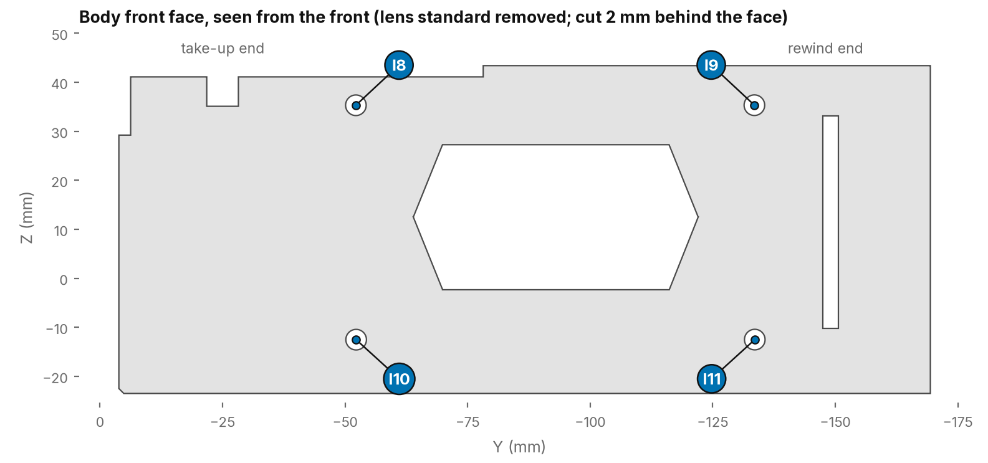
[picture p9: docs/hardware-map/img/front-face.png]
Front face with the lens standard inserts


Figure 2 · Front face seen from the lens side, lens standard removed. I8–I11 are pressed in from the front, level with the face.

Ref | Holds | Where | Hole Ø × depth | Insert | X / Y / Z
I1 | Top cover | Top face, take-up end, front corner | 3.2 × 4.0 | M2 | 53.4 / −9.1 / 41.1
I2 | Top cover | Top face, take-up end, back corner | 3.2 × 4.0 | M2 | 76.4 / −7.8 / 41.1
I3 | Top cover | Top face, front edge beside the take-up bore | 3.2 × 4.0 | M2 | 53.6 / −40.1 / 41.1
I4 | Top cover | Top face, front edge past the gear bay | 3.2 × 4.0 | M2 | 53.1 / −74.7 / 41.1
I5 | Top cover | Top face, back edge past the gear bay | 3.2 × 4.0 | M2 | 80.2 / −73.7 / 41.1
I6 | Cold shoe | Top face, centre of camera, front | 3.3 × 4.0 | M2 | 56.4 / −98.8 / 42.1
I7 | Cold shoe | Top face, centre of camera, back | 3.3 × 4.0 | M2 | 73.4 / −99.2 / 42.1
I8 | Lens standard | Front face, upper, take-up side | 4.2 × 4.0 | M3 | 49.1 / −52.2 / 35.3
I9 | Lens standard | Front face, upper, rewind side | 4.2 × 4.0 | M3 | 49.1 / −133.5 / 35.3
I10 | Lens standard | Front face, lower, take-up side | 4.2 × 4.0 | M3 | 49.1 / −52.3 / −12.5
I11 | Lens standard | Front face, lower, rewind side | 4.2 × 4.0 | M3 | 49.1 / −133.6 / −12.5
I12 | Counter face | Counter gear hub, top | 3.2 × 4.0 | M2 | 67.7 / −63.9 / 48.0
I13 | Advance knob | Inner-ratchet, top hole | 3.2 × 4.0 | M2 | 64.0 / −25.0 / 44.0
I14 | Sprocket gear | Sprocket, top of the shaft | 3.2 × 4.0 | M2 | 73.2 / −45.2 / 30.0

Fitting. For PETG, start the insert tip at about 230 °C. Let the insert sink under its own weight with light pressure, keep it square, and stop when it's flush. Face-down on a flat plate while it's still warm is an easy way to square it up. Stand the body on its base for I1–I7 and lay it on its door side for I8–I11.

I12, I13 and I14. I12's pocket is 4.0 mm deep, so press the insert flush with the top of the hub. I14 goes into the top of the sprocket, and the sprocket gear screws down onto it. I13's hole goes right through into the M1 magnet pocket underneath, so press it flush with the top and check from below that no melted plastic has pushed into the magnet pocket.

## PBall plungers

All of them are D2×3 flanged plungers (Ø2 body, Ø2.5 nose flange, 3 mm long overall, Ø1.5 ball standing 0.4 mm proud of the flange, about 5 N) fitted in radial holes. Amazon ↗ (https://www.amazon.co.uk/s?k=2mm+x+3mm+press+fit+flanged+spring+ball+plunger). Each of P1–P6 opens into a shaft bore and stops short of the outside wall, so P1–P6 go in from inside the bore. The flange sits in its seat flush with the bore wall and the ball points at the shaft.

Rewind bore in the body with plungers P1 to P3

Figure 3 · Rewind bore in the body, 2.8 mm below the top face. Three plungers 120° apart act on the rewind knob.

Take-up bore in the top cover with plungers P4 to P6

Figure 4 · Take-up bore in the top cover. Three plungers 120° apart, the same pattern as the rewind side, ride in the inner-ratchet's W and R detent grooves.

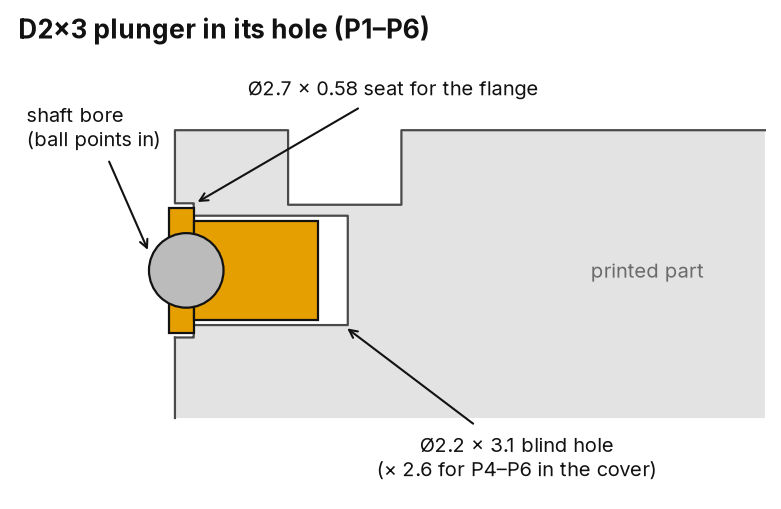
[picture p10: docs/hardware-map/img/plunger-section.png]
One plunger in its hole, in section


Figure 5 · Cross-section of one plunger in its hole (P1–P6; P7 is shown in Figure 11)

Ref | Part | Points from
P1 | Body | Back of the rewind bore
P2 | Body | Front, take-up side of the rewind bore
P3 | Body | Front, rewind-end side of the rewind bore
P4 | Top cover | Back of the take-up bore
P5 | Top cover | Front, take-up end side of the bore
P6 | Top cover | Front, gear-bay side of the bore
P7 | drag-cover only | Tower on the lens side of the dial, at the counter face rim

Fitting. The holes are drawn Ø2.2, 3.1–3.2 mm deep in the body (P1–P3) and 2.6 mm deep in the cover (P4–P6), each behind a Ø2.7 flange seat about 0.6 mm deep. With a 0.4 mm nozzle they print close to Ø2.0, which gives a press fit. Push the plunger body-first from inside the bore with a flat-ended rod until the flange sits in its seat and is level with the bore wall. If one is loose, put a small drop of CA on its body before pressing it in. Keep glue away from the flange and the ball, or the ball will stick. P7's hole is also Ø2.2, 2.8 mm deep behind a Ø2.7 seat set 0.1 mm deeper than the tower face, so its flange stands 0.1 mm proud of the face and 0.1 mm clear of the dial rim. It prints horizontally and may come out slightly oval.

## MMagnets Optional, highly recommended

The camera works without them, but they hold the inner-ratchet firmly down on the spool head, so fit them if you can. Buy: Amazon ↗ (https://www.amazon.co.uk/s?k=5x2mm+neodymium+magnet) (Ø5×2), Amazon ↗ (https://www.amazon.co.uk/s?k=4x2mm+neodymium+magnet) (Ø4×2). All three sit on the take-up axis and hold the inner-ratchet down on the take-up spool head. When the camera is assembled, the Ø5×2 magnet faces the Ø4×2 stack across a gap of about 0.3 mm.

Section through the take-up axis

Figure 6 · Take-up axis cut front to back: countersunk knob screw S12 into I13, magnet M1 directly below it, M2 and M3 in the spool head, and collar C1 under the take-up bore.

Ref | Magnet | Pocket | Fits from
M1 | Ø5 × 2 | Ø5.1 × 2.1 | Underside of the inner-ratchet, pressed to the pocket floor
M2 | Ø4 × 2 | Ø4.1 × 4.2 | Top of the spool head, at the bottom of the pocket
M3 | Ø4 × 2 | same pocket | On top of M2, 0.2 mm below the top of the head

Polarity. The top face of the M2/M3 stack has to attract the exposed face of M1. Let M2 and M3 snap together into a stack first. Then touch M1 to the top of the stack and mark M1's exposed face with a pen dot before separating them. Glue M1 with the dot facing out of its pocket and the stack with its free face up, then check the attraction with the parts dry-fitted before the glue cures.

## SScrews

Each length is the longest standard screw that stays inside its insert without bottoming out. It was worked out from the head seat, the clamped part and the depth of the hole below.

Screws seated in their inserts

Figure 7 · Screws in their inserts, shown in section. The head seats and hole bottoms are taken from the model.

Ref | Screw | Qty | Holds | Into | Room below the tip | Thread in insert | Buy
S1–S5 | M2×6 countersunk (ISO 10642) | 5 | Top cover to body | I1–I5 | 0.2 mm | 3.8 mm | Amazon ↗ (https://www.amazon.co.uk/s?k=M2+x+6+countersunk+socket+screw+ISO+10642+stainless)
S6–S7 | M2×4 countersunk (ISO 10642) | 2 | Cold shoe to body | I6–I7 | 1.3 mm | 2.7 mm | Amazon ↗ (https://www.amazon.co.uk/s?k=M2+x+4+countersunk+socket+screw+ISO+10642+stainless)
S8–S11 | M3×4 socket cap (ISO 4762) or countersunk (ISO 10642) | 4 | Lens standard to body | I8–I11 | 1.5 mm | 2.5 mm | Cap ↗ (https://www.amazon.co.uk/s?k=M3+x+4+socket+cap+screw+ISO+4762+stainless) CSK ↗ (https://www.amazon.co.uk/s?k=M3+x+4+countersunk+socket+screw+ISO+10642+stainless)
S12 | M2×6 countersunk (ISO 10642) | 1 | Advance knob to inner-ratchet | I13 | 1.65 mm to M1 | 2.35 mm | Amazon ↗ (https://www.amazon.co.uk/s?k=M2+x+6+countersunk+socket+screw+ISO+10642+stainless)
S13 | M2×4 thumbscrew, flat underside | 1 | Counter face to counter gear | I12 | 0.9 mm | 3.1 mm | Amazon ↗ (https://www.amazon.co.uk/s?k=M2+x+4+knurled+thumb+screw)
S14 | M2×6 socket cap (ISO 4762) or countersunk (ISO 10642) | 1 | Sprocket gear to sprocket | I14 | 0.25 mm | 4.0 mm | Cap ↗ (https://www.amazon.co.uk/s?k=M2+x+6+socket+cap+screw+ISO+4762+stainless) CSK ↗ (https://www.amazon.co.uk/s?k=M2+x+6+countersunk+socket+screw+ISO+10642+stainless)

Lengths. The cold shoe (M2×4) and lens standard (M3×4) lengths are proven on the printed camera and leave plenty of clearance. The M2×6 cover and sprocket screws are the longest that fit: the next size up bottoms out. The S1–S5 figures are with the cover screwed down, which seats it 0.1 mm below its drawn height. S14 works as a socket cap or a countersunk head, whichever you have, and either way it takes the full depth of its insert, so run it down gently and stop when it seats. Don't go longer on S12 either: an M2×8 would reach 0.35 mm into the M1 magnet pocket.

Heads. The knob's seat for S12 is a Ø3.7 × 90° countersink 0.75 mm deep, so a standard M2 flat head (Ø3.8) finishes level with the knob face and takes 2.35 mm of thread. The countersinks in the cover and cold shoe are Ø3.7–3.8 at 90°, so M2 flat heads finish flush or a hair proud. The lens-standard counterbores are Ø7.3 × 3.1 deep, so either an M3 cap head (Ø5.5 × 3) or an M3 countersunk head sits below the surface.

Counter face on the counter gear, in section

Figure 8 · Counter face held by thumbscrew S13 in insert I12. The head sits in a Ø6.0 × 0.5 mm recess, so a head up to about Ø5.8 sits down in the face.

Counter face. The face starts at 25 and counts up: 25 is the loading position, then winding on takes you to 1, 2, 3 and so on. There is no zero. Lay the face on the hub with 25 against the marker and finger-tighten S13: the marker is the triangle recessed into the cover beside the dial, in the same place on both covers. The face grips on friction, so to reset it for a new roll you loosen the thumbscrew, turn 25 back to the marker, and tighten again. Don't use thread lock.

## CTake-up spool collar Printed part, in the files

C1 is a printed part, not a bought one: print it with the rest of the camera from the files in the repo, where it is named takeup-washer-stopper. It is a split ring (Ø9.5 bore × Ø13.0 × 1.7 mm) that stops the take-up spool lifting out of the body. It sits in the groove just below the spool head (Ø9.3 at the root), directly under the body's take-up bore. The collar is wider than the bore, so once it's in, the spool can't pull up through the top.

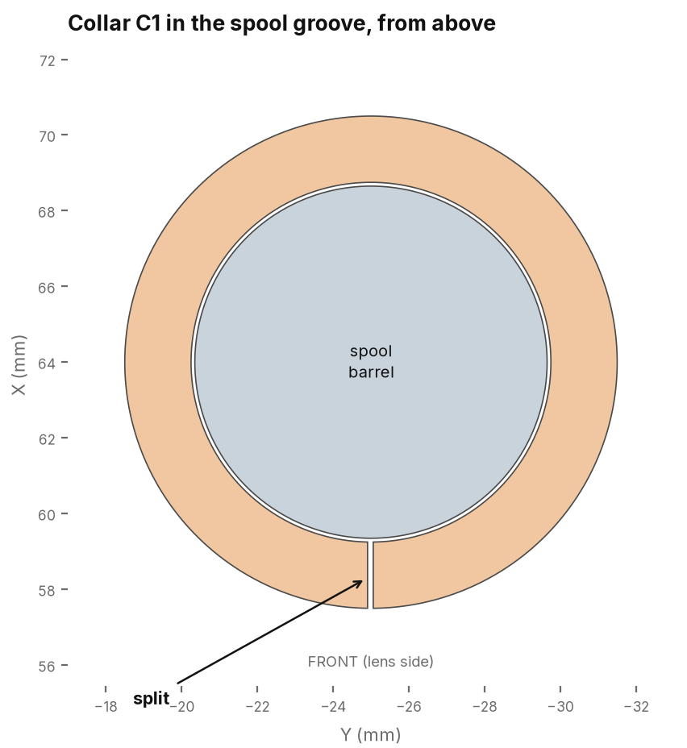
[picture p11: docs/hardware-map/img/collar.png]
Collar in the spool groove, from above


Figure 9 · Collar in the groove, from above. The split is about 0.15 mm wide.

1. Open the body and hold the collar inside it, directly under the take-up bore, with the split facing the lens side.
2. Lower the take-up spool into the body from the top. As it comes down, its bottom end passes through the collar, and the split lets the collar open over the Ø10.8 barrel.
3. Keep lowering the spool until the collar snaps closed in the groove below the head, then spin the spool to check it turns freely without lifting.

## GPressure plate

G1 is one printed part: a rigid platen on a single thin leaf. The leaf joins the platen in the middle and has a bond pad at each end. Glue only the two end pads to the door, never the platen or the middle of the leaf. The door's inside face has a shallow 0.2 mm recess (83.6 × 33.5 mm) that locates the plate, leaving about 1 mm spare at each end and 0.25 mm top and bottom.

Pressure plate in the door

Figure 10 · Pressure plate in the door. Glue goes only on the two end pads, each about 14 × 33 mm, seated on the door face. The lower cut shows the door open, with the platen free.

Gluing. Clean both surfaces with IPA. Put a thin line of CA or a strip of thin double-sided tape on each end pad only. Seat the plate square in the recess with the platen facing the film, and press on the pads alone for 30 seconds. Keep glue out of the gap under the leaf, or the plate stops flexing.

Seating and preload. Both pads sit flat on the door's inside face in the recess. With the door open, the leaf holds the platen 1.6 mm proud of its working position. Closing the door on loaded film pushes the platen back onto the film rails and flexes the leaf by about 0.8 mm, which gives the pressure on the film. Don't shim or glue anything under the leaf to take up that gap.

## P7Counter dial: simple or drag Choose one pair

The counter comes two ways, and you print one pair: simple-cover with simple-counter-face, or drag-cover with drag-counter-face. Everything else is shared: the same body, gears, inserts and screws. Either face also comes as a -two-colour file with the same marker inlay.

| Simple | Drag
Extra hardware | None | One D2×3 ball plunger, P7
How the dial moves | Turns only with the gear train | P7's ball presses on the face's plain rim, with a detent flute at every frame
Marker for 25 | Triangle recessed into the cover | The same triangle, five frames round from P7
Best for | Fewest parts, lightest wind | A dial that stops in the same place every time and doesn't flutter
Costs | The gear backlash lets the face rock a fraction of a frame | One more plunger, a slightly heavier wind, a tower 1 mm above the face

Drag option from above and cut through P7

Figure 11 · Drag option, as fitted: P7 pushes the face and the counter gear 0.14 mm across, until the face meets the cover step on the far side. P7 sits in the tower on drag-cover, which then stays 0.2 mm clear of the rim. Its flange stands 0.1 mm proud of the tower face and 0.1 mm clear of the rim, and its ball runs on drag-counter-face's plain rim, dropping 0.15 mm into a 120° V-flute under each frame marker. The triangle marker is exactly five frames (72°) round from P7, so a flute sits under the ball whenever a number sits at the triangle.

Fitting the drag option. Press P7 in from the dial side before the counter face goes on. Then tighten S13 firmly by hand: it has to hold the face against P7's friction and the pull of each flute as well as the gears. Wind through a few frames and check the face stays with the train; if it slips on the hub, tighten S13 a little more. Print the pair together: the simple face has no flutes, so on the drag cover it drags without clicking, and the drag face needs the drag cover's tower, which sits 0.14 mm nearer the dial than the 2.1.0 one.

## G2Two-piece body seam Two-piece body only

Skip this if you printed the one-piece body. The two halves meet on a flat seam about 34 mm above the base. The bottom half carries a 2 mm ridge that runs right around the film chambers and the film path; the top half has the matching groove. Light arriving along the glue line has to climb over that step to reach the film, which is why only the chambers and the path are ridged and the rest of the seam is plain.

Four alignment pegs set the halves: Ø3.8 × 2 mm posts inside the top half's groove, dropping into Ø4 mm holes in the ridge. Dry-fit before any glue. The halves should sit down with no rock and no light gap at the seam; if they rock, the ridge is not seating and the groove needs a clean-up rather than more clamp.

Gluing. Fit every insert, plunger and magnet first, while the halves are still separate and easy to hold. Then run a thin bead of CA or epoxy on the flat land outside the ridge, press the halves together on the pegs, and clamp lightly until it cures. Keep glue off the ridge crest and out of the groove, or the halves will stand proud and leave the gap you were trying to close.

## TTripod socket

The socket is printed, not an insert: a 3/8"-16 thread moulded straight into the base on the centreline, five turns and 8.5 mm deep, at 67.4 / −86.1 / −23.5. Nothing is pressed or glued into it.

Most tripods and quick-release plates are 1/4"-20, so fit a 3/8" to 1/4" bushing and leave it in. Amazon ↗ (https://www.amazon.co.uk/s?k=3%2F8+to+1%2F4+tripod+bushing+adapter+screw)

First thread. Start the bushing by hand and stop as soon as it seats. A printed thread strips if you drive it with a tool, and a 1/4" screw run straight into the 3/8" hole will tear it out. If the thread is tight from the print, run the bushing in and out a couple of times to clear it rather than cutting it.

## OFrom the original build

These are unchanged from Denis's build and are not in the printed files. The remix needs all of them.

Item | What for | Buy
Black flocked self-adhesive paper | Lining the film chambers and the inside of the door to kill reflections and stray light. Full-size templates are in flocking/ in the repo. | Amazon ↗ (https://www.amazon.co.uk/s?k=self+adhesive+flock+paper+black+light+trap)
Black light-seal foam | Sealing the door where it closes onto the body | Amazon ↗ (https://www.amazon.co.uk/s?k=camera+light+seal+foam+kit+black)
Rigid stainless wire, 0.6–0.8 mm | Springs and linkages in the original mechanism | Amazon ↗ (https://www.amazon.co.uk/s?k=0.8mm+stainless+steel+spring+wire)
Superglue (CA) | Magnets, the pressure plate pads, and the body seam on the two-piece body | Amazon ↗ (https://www.amazon.co.uk/s?k=cyanoacrylate+superglue+gel)

Order. Flocking and foam go in last, after everything else is fitted and the camera has been dry-run with the back open. They are the one thing you cannot fit around.

Infidex 176 V x IDENTIDEM.design Remix. Camera: Infidex 176 V (https://github.com/max05210238/Infidex_176_V), an open source project by Denis Aminev (Time to Waste) (https://www.youtube.com/@time_to_waste). Remix and guide by IDENTIDEM.design.

Buy links open an Amazon UK search for that exact part rather than one listing, so check the size, head type and length before ordering. Measured from the remix CAD assembly, 27 September 2026. Where the CAD and a printed part disagree, go by the print.

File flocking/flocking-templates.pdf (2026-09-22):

# Flocking templates: light chamber and pressure plate

Infidex 176 V x IDENTIDEM.design remix. Fits the one-piece and the two-piece body.
Print at 100% ("Actual size", no fit to page), then check the 50 mm bar before cutting.
Sizes allow 0.5 mm flocked paper and 0.2 mm fitting clearance per edge. T, B, R1 and R2 are narrower than the chamber so they sit between the side pieces. Every piece is symmetric, so either side can face up. Fit order: S (both), then T and B, then R1 and R2. Leave the film gate opening and its throat bare.
P goes on the film face of the platen, centred, with 0.2 mm of platen showing all round.

50 mm: measure this before cutting

T
70.60 x 23.53 mm

B
70.60 x 23.28 mm

S (1/2)
20.78 x
39.20 mm

S (2/2)
20.78 x
39.20 mm

R1
70.60 x 9.10 mm

R2 70.60 x 4.75 mm

P
77.08 x 32.63 mm
Piece | Qty Where
T | 1 | Chamber ceiling, tab towards the lens 70.60 x 23.53 mm, dxf/chamber-top.dxf
B | 1 | Chamber floor, tab towards the lens 70.60 x 23.28 mm, dxf/chamber-bottom.dxf
S | 2 | Left and right chamber walls 20.78 x 39.20 mm, dxf/chamber-side.dxf
R1 | 1 | Rear wall below the film gate (optional) 70.60 x 9.10 mm, dxf/rear-wall-lower.dxf
R2 | 1 | Rear wall above the film gate (optional) 70.60 x 4.75 mm, dxf/rear-wall-upper.dxf
P | 1 | Pressure plate, on the platen face 77.08 x 32.63 mm, dxf/pressure-plate.dxf

Chamber from the CAD: 72.00 wide x 39.60 high x 21.18 deep at the corners, with a 58.5 mm recess at the front centre (2.75 mm ceiling, 2.5 mm floor). Pressure plate platen face: 77.48 x 33.03.

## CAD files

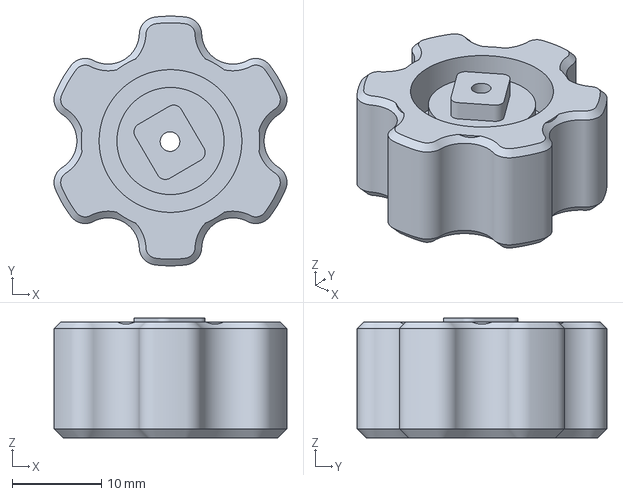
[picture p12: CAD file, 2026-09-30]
3mf/parts/advance-knob-two-colour.3mf
26.1 x 28.0 x 13.4 mm

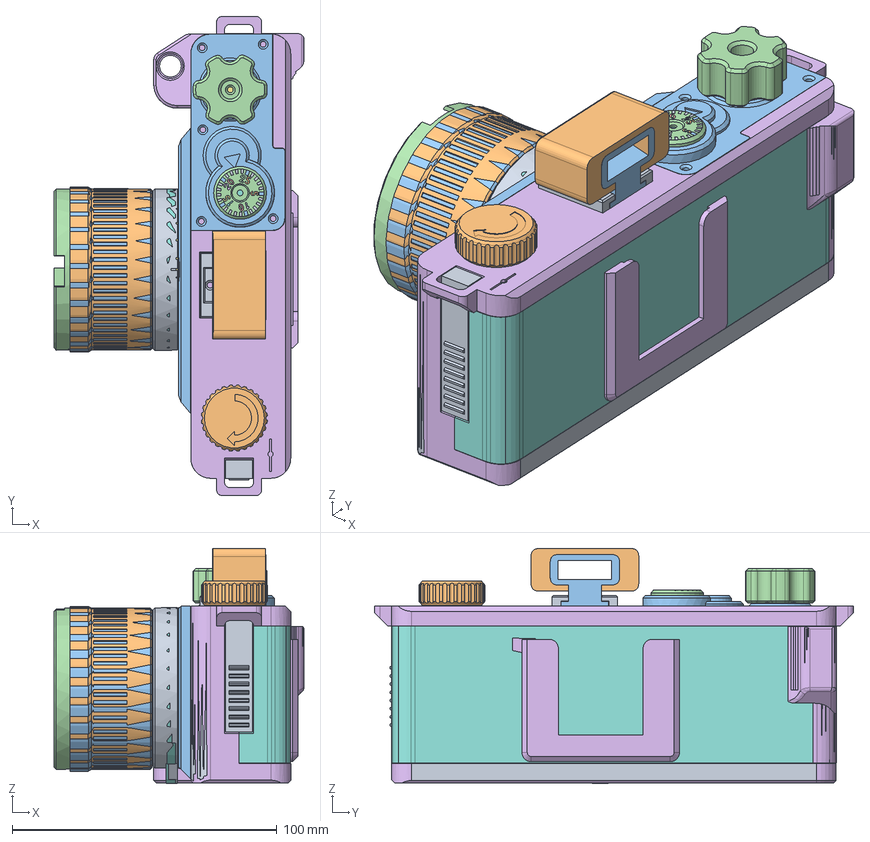
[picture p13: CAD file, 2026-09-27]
cad/Infidex176V-IDENTIDEM.design-remix.step
94.5 x 181.0 x 88.9 mm

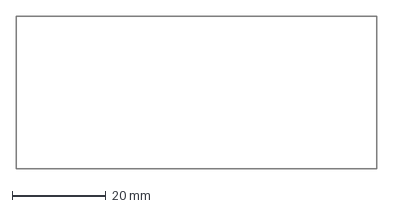
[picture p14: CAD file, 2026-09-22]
flocking/dxf/pressure-plate.dxf
77.1 x 32.6 mm

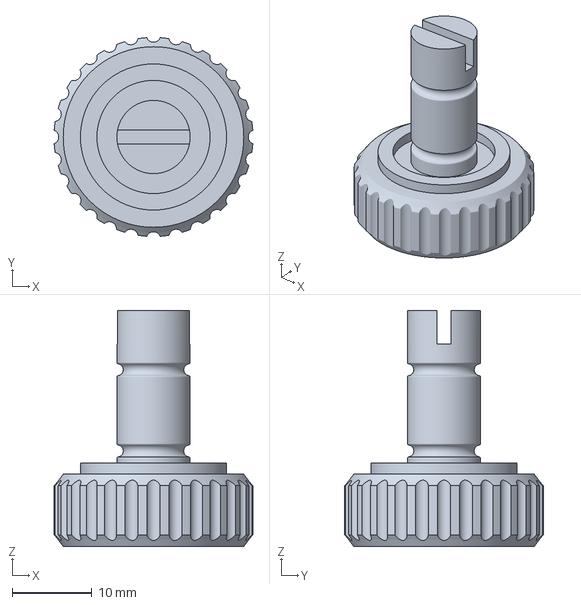
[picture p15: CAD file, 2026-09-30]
3mf/parts/rewind-knob-two-colour.3mf
25.0 x 25.0 x 29.7 mm

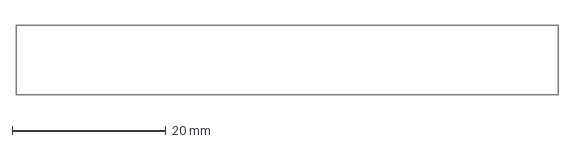
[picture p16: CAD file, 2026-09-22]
flocking/dxf/rear-wall-lower.dxf
70.6 x 9.10 mm

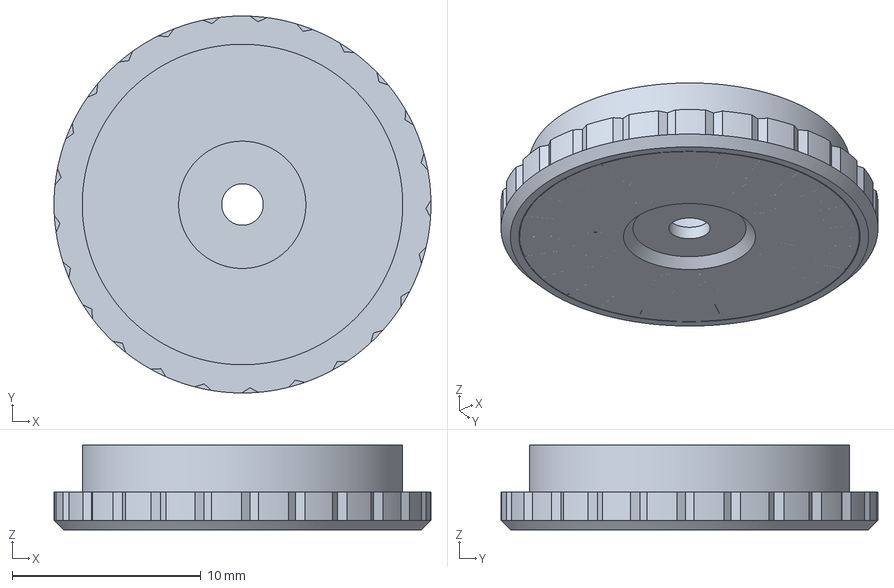
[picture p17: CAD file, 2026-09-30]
3mf/parts/drag-counter-face-two-colour.3mf
20.0 x 20.0 x 4.50 mm

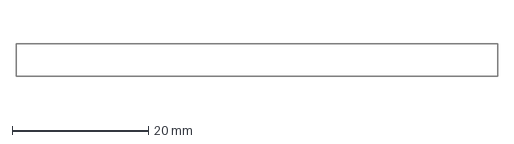
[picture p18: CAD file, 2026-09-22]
flocking/dxf/rear-wall-upper.dxf
70.6 x 4.75 mm

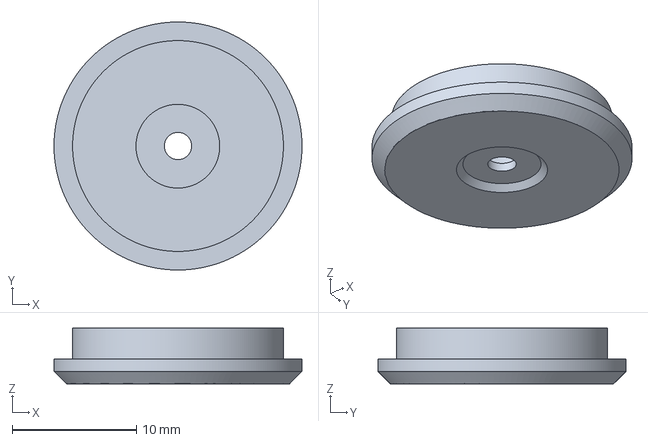
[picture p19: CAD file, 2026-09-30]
3mf/parts/simple-counter-face-two-colour.3mf
20.0 x 20.0 x 4.50 mm

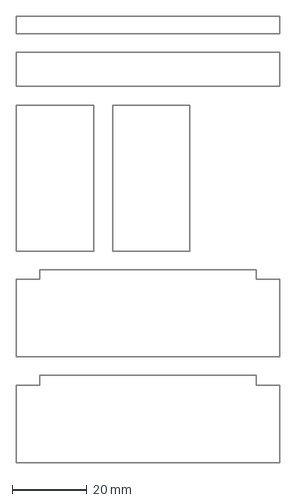
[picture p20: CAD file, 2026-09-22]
flocking/dxf/all-pieces.dxf
70.6 x 119.9 mm

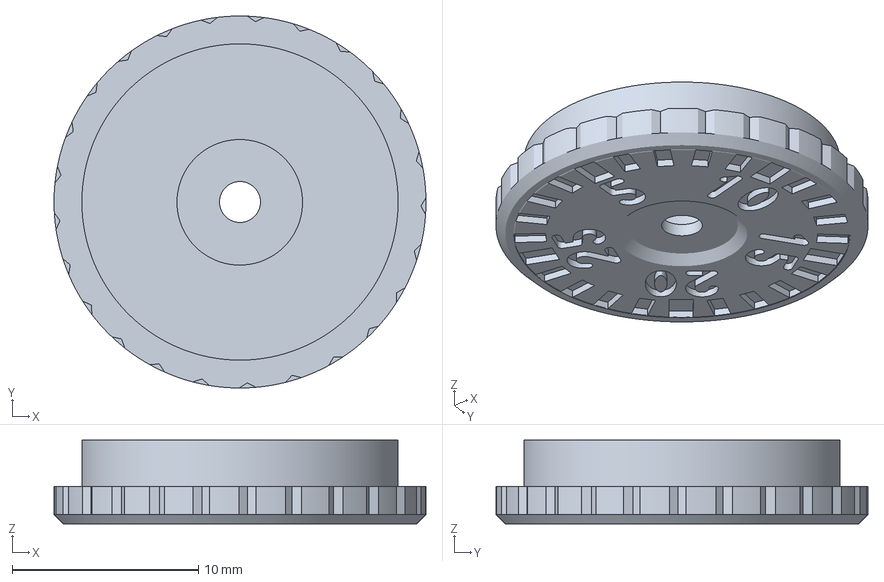
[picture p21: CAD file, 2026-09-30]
3mf/parts/drag-counter-face.3mf
20.0 x 20.0 x 4.50 mm

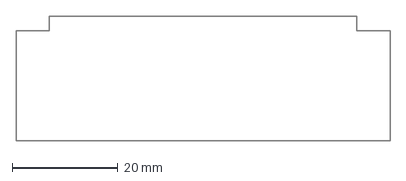
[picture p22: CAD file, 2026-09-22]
flocking/dxf/chamber-top.dxf
70.6 x 23.5 mm

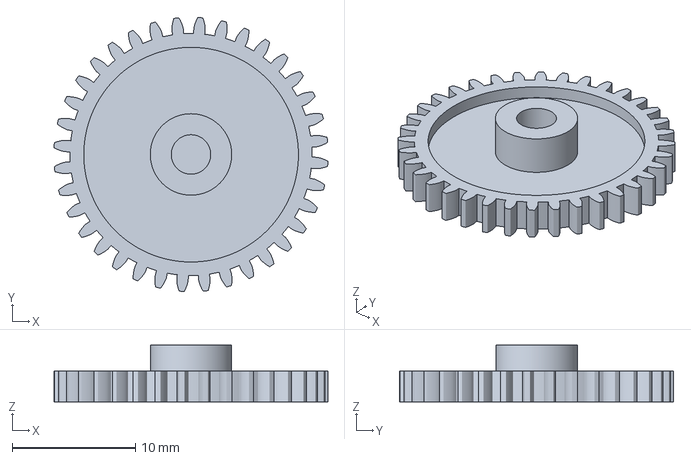
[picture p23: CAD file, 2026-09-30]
3mf/parts/counter-gear.3mf
22.2 x 22.2 x 4.60 mm

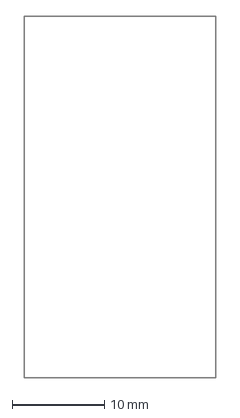
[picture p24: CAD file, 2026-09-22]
flocking/dxf/chamber-side.dxf
20.8 x 39.2 mm

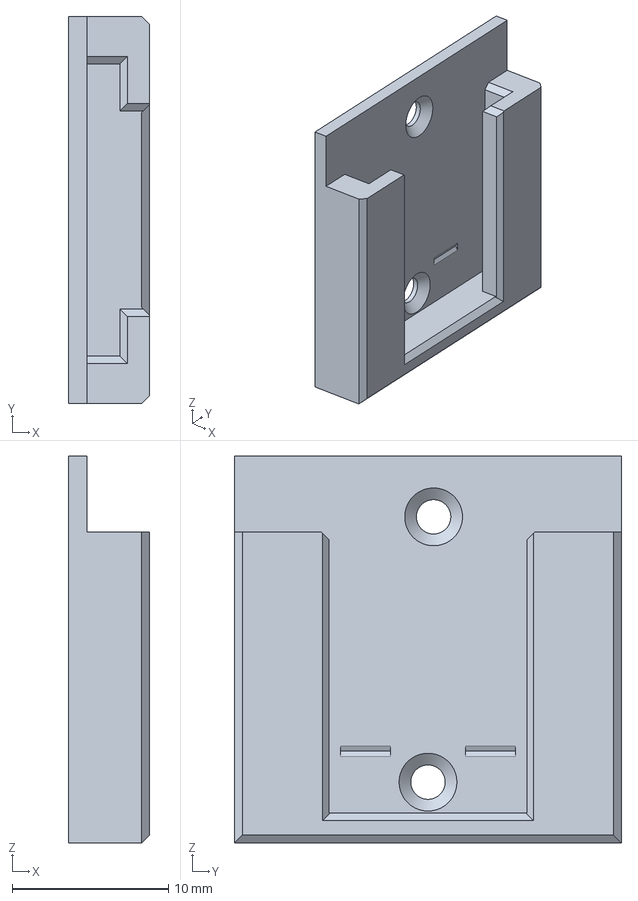
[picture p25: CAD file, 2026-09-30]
3mf/parts/cold-shoe.3mf
5.18 x 24.8 x 24.8 mm

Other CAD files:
flocking/dxf/chamber-bottom.dxf
3mf/parts/simple-counter-face.3mf
3mf/parts/drag-cover.3mf
3mf/parts/advance-knob.3mf
3mf/Infidex176V-IDENTIDEM.design-remix.3mf
3mf/parts/body-bottom.3mf
3mf/parts/body-solid.3mf
3mf/parts/body-top.3mf
3mf/parts/counter-coupling-gear.3mf
3mf/parts/counter-idler-1.3mf
3mf/parts/counter-idler-2.3mf
3mf/parts/door-var-1.3mf
3mf/parts/door-var-2.3mf
3mf/parts/door-var-3.3mf
3mf/parts/door-var-4.3mf
3mf/parts/helicoid-fix-ring.3mf
3mf/parts/helicoid-focus-ring-no-ribs.3mf
3mf/parts/helicoid-focus-ring-ribs.3mf
3mf/parts/helicoid-inner-ring-for-55mm-lens.3mf
3mf/parts/helicoid-inner-ring-for-80mm-lens.3mf
3mf/parts/helicoid-lens-board.3mf
3mf/parts/helicoid-mount.3mf
3mf/parts/inner-ratchet.3mf
3mf/parts/latch.3mf
3mf/parts/pressure-plate-1.3mf
3mf/parts/ratchet-coupling-gear.3mf
3mf/parts/rewind-knob.3mf
3mf/parts/simple-cover.3mf
3mf/parts/sprocket.3mf
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

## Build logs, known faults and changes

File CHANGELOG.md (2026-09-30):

# Changelog

Every release lists what changed, the commits behind it and which parts to reprint.

## Versioning

Versions follow [Semantic Versioning](https://semver.org), read for printed parts:

- **Major**: parts from the previous release no longer fit or mesh with the new ones, so a set of parts has to be reprinted together, or the bought hardware changes.
- **Minor**: new parts, variants, templates or tools. Existing builds are unaffected.
- **Patch**: fixes you pick up by reprinting only the listed parts, each on its own, plus re-exports, mesh repairs and documentation.

Releases are tagged `vX.Y.Z`. Changes that only touch the documentation go into the next release rather than getting a release of their own.

## [Unreleased]

## [2.3.0] - 2026-09-30

Two-colour knobs, and every figure in the hardware guide is now drawn from the CAD. Existing builds are unaffected.

**Reprint:** nothing. For the knobs' direction arrows in a second colour, print `advance-knob-two-colour` and `rewind-knob-two-colour` instead of the one-colour knobs.

### Added

- `advance-knob-two-colour.3mf` and `rewind-knob-two-colour.3mf`: each knob with an inlay that fills its 1.0 mm arrow recess, for the arrows in a second filament. The one-colour knobs are unchanged. [`90f7198`](https://github.com/acornelissen/Infidex_176_v_IDENTIDEM_design_remix/commit/90f7198)
- `mise run figures` draws all eleven guide figures from the STEP, and `mise run add -- <part>-inlay --inlay-for <part>` gives an existing part a two-colour file. [`a85f57f`](https://github.com/acornelissen/Infidex_176_v_IDENTIDEM_design_remix/commit/a85f57f), [`416b7d0`](https://github.com/acornelissen/Infidex_176_v_IDENTIDEM_design_remix/commit/416b7d0)

### Fixed

- `mise run export` keeps a part that only moved in the assembly where it is on the bed. [`117b8d4`](https://github.com/acornelissen/Infidex_176_v_IDENTIDEM_design_remix/commit/117b8d4)
- The README and the guide: plunger hole depths, the magnet gap, the collar's size and the platen's lift, measured from the STEP. [`10055dd`](https://github.com/acornelissen/Infidex_176_v_IDENTIDEM_design_remix/commit/10055dd)

## [2.2.0] - 2026-09-30

The drag dial now clicks onto each frame, and the repository gains tools that check the 3MFs against the STEP. Existing builds are unaffected.

**Reprint:** nothing, unless you want the new counter parts. For a drag dial that clicks onto each frame, reprint `drag-cover` and `drag-counter-face` (or `drag-counter-face-two-colour`) together. Reprint `cold-shoe` only if you want the ISO 518 shoe. The marker position and the knob arrows are cosmetic, so reprint the covers or knobs only for those if you want them.

### Added

- `drag-counter-face` has a detent flute under every frame marker: 25 vertical V-flutes, 120° included, 0.27 mm deep in a plain rim that replaces the ball groove. P7's ball seats on the flute's flanks and drops 0.15 mm, so the face settles with the number centred on the marker and clicks there firmly. [`a72c8d3`](https://github.com/acornelissen/Infidex_176_v_IDENTIDEM_design_remix/commit/a72c8d3), [`3f40a5f`](https://github.com/acornelissen/Infidex_176_v_IDENTIDEM_design_remix/commit/3f40a5f), [`0711087`](https://github.com/acornelissen/Infidex_176_v_IDENTIDEM_design_remix/commit/0711087)
- Engraved arrows on `advance-knob` and `rewind-knob` show which way each one turns. [`3f40a5f`](https://github.com/acornelissen/Infidex_176_v_IDENTIDEM_design_remix/commit/3f40a5f)
- `mise run verify`, `export`, `add`, `plates` and `clearance` check the 3MFs and the counter parts against the STEP, re-export or add parts in place, and manage the project's plates. `mise run guide` and `mise run figures` rebuild the hardware guide. CI runs the tests on every push and the 3MF checks when the CAD, 3MFs or tools change. See [`tools/README.md`](tools/README.md).
- The counter-train script takes a tooth count for each pinion.

### Changed

- The project file gives each counter choice its own plate: plate 10 `simple-cover`, 11 `drag-cover`, 12 the idlers, 13 `simple-counter-face`, 14 `drag-counter-face`. Print the plates for the dial you chose; there is nothing to delete first. The shared counter gears stay on Small parts 2, and with 14 plates Bambu Studio lays them out in four columns. [`71851bb`](https://github.com/acornelissen/Infidex_176_v_IDENTIDEM_design_remix/commit/71851bb)
- `drag-cover`'s tower and P7 sit 0.14 mm nearer the dial. P7 pushes the face across by that much until it meets the cover step, which the first flutes didn't allow for: the ball ran out of travel before it reached a flute, so the face rocked at every frame. [`0711087`](https://github.com/acornelissen/Infidex_176_v_IDENTIDEM_design_remix/commit/0711087)
- `cold-shoe` is drawn to ISO 518. It has the same footprint and the same two countersunk holes for S6–S7, so it fits the body as before. [`f9359b2`](https://github.com/acornelissen/Infidex_176_v_IDENTIDEM_design_remix/commit/f9359b2)
- `drag-cover` uses the same triangle marker as `simple-cover` instead of the arrow on the tower. On both covers the triangle moves 6° round the dial, to exactly five frames from P7, so the detent centres each number on it. `advance-knob`'s bore entry chamfer is 0.5 mm instead of 1 mm. [`3f40a5f`](https://github.com/acornelissen/Infidex_176_v_IDENTIDEM_design_remix/commit/3f40a5f)

### Fixed

- In the CAD, `viewfinder-var-1` sits on the cold-shoe floor like `viewfinder-var-2` instead of 0.03 mm into it. Its printed shape is unchanged, so there is nothing to reprint. [`3bfa478`](https://github.com/acornelissen/Infidex_176_v_IDENTIDEM_design_remix/commit/3bfa478)
- The README and hardware guide: insert sizes, the part file for each idler, where P7 goes in, and other wording. [`638c877`](https://github.com/acornelissen/Infidex_176_v_IDENTIDEM_design_remix/commit/638c877)

## [2.1.0] - 2026-09-27

A choice of counter dial: the existing free-running one, or a new one held by a ball plunger so it reads the same every time. Existing builds are unaffected.

**Reprint:** nothing. To switch to the drag option, print `drag-cover` and `drag-counter-face` as a pair and fit one more D2×3 ball plunger (P7).

### Added

- `drag-cover` and `drag-counter-face`, a matched pair offered as an alternative to the simple cover and counter face. A tower beside the dial, 0.2 mm clear of the face rim, holds a seventh ball plunger, P7, in the same Ø2.2 hole as the others. Its ball runs in a 0.12 mm groove round the rim. The friction keeps the backlash taken up so the dial stops in the same place and doesn't flutter. The marker for 25 is an arrow on top of the tower. [`13bc08e`](https://github.com/acornelissen/Infidex_176_v_IDENTIDEM_design_remix/commit/13bc08e)
- `drag-counter-face-two-colour.3mf`, with the same marker inlay as the simple face. [`13bc08e`](https://github.com/acornelissen/Infidex_176_v_IDENTIDEM_design_remix/commit/13bc08e)
- In the project file, `drag-cover` is on plate 7 beside the simple cover and `drag-counter-face` is on plate 8 beside the simple face. Print one of each pair. [`13bc08e`](https://github.com/acornelissen/Infidex_176_v_IDENTIDEM_design_remix/commit/13bc08e)
- The README and the hardware guide explain how to choose between the two dials, and the guide has a drawing of P7 (Figure 11). [`a93a39c`](https://github.com/acornelissen/Infidex_176_v_IDENTIDEM_design_remix/commit/a93a39c)

### Changed

- `cover` and `counter-face` are renamed `simple-cover` and `simple-counter-face`, in the STEP, the part 3MFs and the project file, and `counter-face-two-colour.3mf` becomes `simple-counter-face-two-colour.3mf`. Their geometry is unchanged. [`13bc08e`](https://github.com/acornelissen/Infidex_176_v_IDENTIDEM_design_remix/commit/13bc08e)
- The parametric counter-train model has the 2.0.2 idler bores, so it matches the main model again. [`d89cc10`](https://github.com/acornelissen/Infidex_176_v_IDENTIDEM_design_remix/commit/d89cc10)

## [2.0.2] - 2026-09-27

Closer-running counter idlers, and a sprocket that no longer binds in the body. The new parts fit a 2.0.1 build.

**Reprint:** `counter-coupling-gear`, `counter-idler-1` and `counter-idler-2`. Reprint your body (`body-solid`, or `body-top`) only if the sprocket binds in it.

### Fixed

- The idler bores are 0.2 mm over their pins, down from 0.4 mm: `counter-coupling-gear` from Ø4.4/Ø3.6 to Ø4.2/Ø3.4, `counter-idler-1` from Ø3.61 to Ø3.4 and `counter-idler-2` from Ø3.6 to Ø3.4. Face heights and outer dimensions are unchanged. [`3587f2b`](https://github.com/acornelissen/Infidex_176_v_IDENTIDEM_design_remix/commit/3587f2b)
- The body's hole for the sprocket shaft is Ø6.2, up from Ø5.8, which was tighter than the Ø6.0 shaft. [`26c1d61`](https://github.com/acornelissen/Infidex_176_v_IDENTIDEM_design_remix/commit/26c1d61)

### Changed

- The counter-train generator defaults match the new bores. [`3587f2b`](https://github.com/acornelissen/Infidex_176_v_IDENTIDEM_design_remix/commit/3587f2b)
- The README gives the idler bore sizes and how to free a tight idler.

## [2.0.1] - 2026-09-25

Tighter tolerances where printed parts showed gaps. The new parts fit a 2.0.0 build.

**Reprint:** `cover`, `sprocket` and `ratchet-coupling-gear`.

### Fixed

- Tighter tolerances on the `cover`, `sprocket` and `ratchet-coupling-gear`, which printed with gaps. Outer dimensions are unchanged. [`b55eabc`](https://github.com/acornelissen/Infidex_176_v_IDENTIDEM_design_remix/commit/b55eabc)
- I12 sits at Z 48.0, not 47.8, so S13 has 0.9 mm below its tip and 3.1 mm of thread. The thumbscrew recess is Ø6.0, not Ø5.8.
- S1–S5 figures are given with the cover screwed down: 0.2 mm below the tip and 3.8 mm of thread.

### Changed

- The hardware guide is rebuilt from a source in `docs/hardware-map/`, and its fitting order and the README's now include the counter gears. Figure 8 is redrawn from the current counter face.
- The README documents the cover's locating boss, the two-colour counter face and the flocking templates.

## [2.0.0] - 2026-09-24

The counter gear train is reworked so it turns freely with the cover screwed down. The body, the cover and the counter gears change together, so reprint them as a set.

**Reprint:** your body (`body-solid`, or `body-top` for the two-piece body), `cover`, `ratchet-coupling-gear`, `counter-coupling-gear`, `counter-idler-1`, `counter-idler-2`, `counter-gear` and `counter-face` (or `counter-face-two-colour`).

### Changed

- The cover sits 0.1 mm lower than drawn once it is screwed down. Every gear now keeps at least 0.3 mm of end float with the cover seated. The changes are higher pocket ceilings and underside reliefs in the cover, a relief under the dial sweep, bores through each idler, trimmed faces where gears stack, and a counter face bore that centres the dial wheel. [`a5eedc9`](https://github.com/acornelissen/Infidex_176_v_IDENTIDEM_design_remix/commit/a5eedc9)
- Deeper tooth engagement: the contact ratio rises from 1.22 to 1.32, and the backlash per mesh drops from 0.25 to 0.20 mm. [`db5c098`](https://github.com/acornelissen/Infidex_176_v_IDENTIDEM_design_remix/commit/db5c098), [`a5eedc9`](https://github.com/acornelissen/Infidex_176_v_IDENTIDEM_design_remix/commit/a5eedc9)
- A 25 mm boss on the body around the dial locates the cover in a 25.2 mm recess. [`390df7f`](https://github.com/acornelissen/Infidex_176_v_IDENTIDEM_design_remix/commit/390df7f)
- Idler pins: idler 2 turns on a single 3.2 mm pin in a 3.6 mm bore. The idler 3 pin stops level with the body's top face, so `body-top` prints flat. [`390df7f`](https://github.com/acornelissen/Infidex_176_v_IDENTIDEM_design_remix/commit/390df7f), [`91efaf5`](https://github.com/acornelissen/Infidex_176_v_IDENTIDEM_design_remix/commit/91efaf5), [`305fd5e`](https://github.com/acornelissen/Infidex_176_v_IDENTIDEM_design_remix/commit/305fd5e)
- Larger frame markers, from 0.5 x 0.8 mm up to 0.9 x 1.7 mm and 1.3 x 1.9 mm beside the numbers. Markers and numbers are now 0.4 mm deep, so they survive first-layer squish. [`4411970`](https://github.com/acornelissen/Infidex_176_v_IDENTIDEM_design_remix/commit/4411970)

### Added

- `counter-face-two-colour.3mf`, a flush inlay for printing the markers in a second filament. [`4411970`](https://github.com/acornelissen/Infidex_176_v_IDENTIDEM_design_remix/commit/4411970)
- The STEP includes the counter face inlay. [`390df7f`](https://github.com/acornelissen/Infidex_176_v_IDENTIDEM_design_remix/commit/390df7f)
- Counter-train generator: a contact ratio check, plus face heights, stepped bores and a tooth phase for every gear, with an axial clash check. Its defaults rebuild the gears in the main model. [`db5c098`](https://github.com/acornelissen/Infidex_176_v_IDENTIDEM_design_remix/commit/db5c098), [`c35d43b`](https://github.com/acornelissen/Infidex_176_v_IDENTIDEM_design_remix/commit/c35d43b), [`74720a9`](https://github.com/acornelissen/Infidex_176_v_IDENTIDEM_design_remix/commit/74720a9)

### Fixed

- A non-manifold edge under the chamber rear wall in `body-solid` and `body-bottom`, carried since 1.0.0. Nothing on the outside changes, and both meshes are now watertight. You don't need to reprint `body-bottom` for this. [`61afe50`](https://github.com/acornelissen/Infidex_176_v_IDENTIDEM_design_remix/commit/61afe50)

## [1.1.0] - 2026-09-22

**Reprint:** nothing.

### Added

- Flocking templates for the light chamber: a full-size A4 PDF and per-piece DXF outlines, sized for both bodies. [`66a04ff`](https://github.com/acornelissen/Infidex_176_v_IDENTIDEM_design_remix/commit/66a04ff)
- A pressure plate piece in the flocking templates. [`15b3fc9`](https://github.com/acornelissen/Infidex_176_v_IDENTIDEM_design_remix/commit/15b3fc9)

## [1.0.1] - 2026-09-21

**Reprint:** `cover`. Also `sprocket` and `ratchet-coupling-gear` if you printed them from the 1.0.0 3MFs.

### Fixed

- Tighter tolerances on the gear train cover. [`0768d04`](https://github.com/acornelissen/Infidex_176_v_IDENTIDEM_design_remix/commit/0768d04)
- `sprocket` and `ratchet-coupling-gear` 3MFs re-exported from the current CAD. The sprocket gains its through-all Ø3.2 hole for the I14 insert, and the ratchet-coupling-gear's Ø4 bore is 9.0 mm deep instead of 7.0 mm. [`67ad28a`](https://github.com/acornelissen/Infidex_176_v_IDENTIDEM_design_remix/commit/67ad28a)

### Changed

- The README points at the original assembly guide and the upstream lens mount options. [`c6bfee0`](https://github.com/acornelissen/Infidex_176_v_IDENTIDEM_design_remix/commit/c6bfee0)

## [1.0.0] - 2026-09-18

First release of the remix.

### Added

- Remixed camera CAD (Fusion and STEP) and the print-ready Bambu project. [`795b37c`](https://github.com/acornelissen/Infidex_176_v_IDENTIDEM_design_remix/commit/795b37c)
- One 3MF per part. [`1bbc604`](https://github.com/acornelissen/Infidex_176_v_IDENTIDEM_design_remix/commit/1bbc604)
- Parametric counter-train Fusion script with tests. [`35278fa`](https://github.com/acornelissen/Infidex_176_v_IDENTIDEM_design_remix/commit/35278fa)
- Hardware placement guide and section drawings. [`142e6cd`](https://github.com/acornelissen/Infidex_176_v_IDENTIDEM_design_remix/commit/142e6cd)
- README with parts, hardware and the full assembly procedure. [`96984c0`](https://github.com/acornelissen/Infidex_176_v_IDENTIDEM_design_remix/commit/96984c0), [`238e9ea`](https://github.com/acornelissen/Infidex_176_v_IDENTIDEM_design_remix/commit/238e9ea)
- Attribution notice for the original project. [`f6cef08`](https://github.com/acornelissen/Infidex_176_v_IDENTIDEM_design_remix/commit/f6cef08)

[Unreleased]: https://github.com/acornelissen/Infidex_176_v_IDENTIDEM_design_remix/compare/v2.3.0...HEAD
[2.3.0]: https://github.com/acornelissen/Infidex_176_v_IDENTIDEM_design_remix/compare/v2.2.0...v2.3.0
[2.2.0]: https://github.com/acornelissen/Infidex_176_v_IDENTIDEM_design_remix/compare/v2.1.0...v2.2.0
[2.1.0]: https://github.com/acornelissen/Infidex_176_v_IDENTIDEM_design_remix/compare/v2.0.2...v2.1.0
[2.0.2]: https://github.com/acornelissen/Infidex_176_v_IDENTIDEM_design_remix/compare/v2.0.1...v2.0.2
[2.0.1]: https://github.com/acornelissen/Infidex_176_v_IDENTIDEM_design_remix/compare/v2.0.0...v2.0.1
[2.0.0]: https://github.com/acornelissen/Infidex_176_v_IDENTIDEM_design_remix/compare/v1.1.0...v2.0.0
[1.1.0]: https://github.com/acornelissen/Infidex_176_v_IDENTIDEM_design_remix/compare/v1.0.1...v1.1.0
[1.0.1]: https://github.com/acornelissen/Infidex_176_v_IDENTIDEM_design_remix/compare/v1.0.0...v1.0.1
[1.0.0]: https://github.com/acornelissen/Infidex_176_v_IDENTIDEM_design_remix/releases/tag/v1.0.0

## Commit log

2026-09-18 feat: add remixed camera CAD and print-ready files
    [Infidex176V-IDENTIDEM.design-remix-counter-train.f3d, Infidex176V-IDENTIDEM.design-remix.3mf, Infidex176V-IDENTIDEM.design-remix.f3d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]
2026-09-18 refactor: move CAD sources into cad/
    [Infidex176V-IDENTIDEM.design-remix-counter-train.f3d, Infidex176V-IDENTIDEM.design-remix.f3d, Infidex176V-IDENTIDEM.design-remix.step]
2026-09-18 refactor: move the print project into 3mf/
    [Infidex176V-IDENTIDEM.design-remix.3mf]
2026-09-18 feat: add a separate 3MF export for every part
    [advance-knob.3mf, body-bottom.3mf, body-solid.3mf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]
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2026-09-19 docs: point at the original assembly guide and the upstream lens mount options
2026-09-21 Slightly tightened tolerances on the gear train cover after some feedback.
    [Infidex176V-IDENTIDEM.design-remix.3mf, Infidex176V-IDENTIDEM.design-remix.f3d, Infidex176V-IDENTIDEM.design-remix.step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]
2026-09-21 fix(3mf): re-export sprocket and ratchet-coupling-gear from current CAD
    Both meshes in the print project and the standalone part files predated
    the current Fusion design. The sprocket now has the through-all Ø3.2
    hole for the I14 insert, and the ratchet-coupling-gear's Ø4 bore is
    9.0 mm deep instead of 7.0 mm. All other parts already matched.
    [Infidex176V-IDENTIDEM.design-remix.3mf, ratchet-coupling-gear.3mf, sprocket.3mf]
2026-09-22 docs: add flocking templates for the remix light chamber
    Full-size A4 PDF and per-piece DXF outlines, sized from the CAD for both
    bodies, with a README section on sizes, allowances and fitting order.
    [all-pieces.dxf, chamber-bottom.dxf, chamber-side.dxf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]
2026-09-22 docs: add the pressure plate to the flocking templates
    [pressure-plate.dxf]
2026-09-22 feat(tools): check contact ratio and deepen tooth engagement
    Add contact_ratio() with tests that every mesh stays at 1.3 or more as
    drawn and still at least 1.0 with its axes 0.2 mm apart. To meet them,
    the pinion tip shave drops from 0.21 to 0.10 mm and tooth thinning from
    0.125 to 0.10 mm, taking the contact ratio from 1.22 to 1.32 and the
    backlash per mesh from 0.25 to 0.20 mm.
2026-09-22 fix(counter): free up and centre the counter gear train
    The top cover seats on its recess floor once screwed down, 0.1 mm lower
    than drawn, which left idler 3's pinion pressed into the cover, the dial
    rubbing a body wall and several gears 0.1 mm apart. Every gear now keeps
    at least 0.3 mm of end float with the cover seated:
    - cover: higher pocket ceilings over idler 3, underside reliefs over the
    sprocket pinion and idler 2, dial step bore 17.25 mm
    - body: relief under the dial sweep, 9.4 mm sprocket pinion pocket, and
    pins that run nearly the full height of each idler
    - gears: bores through each idler, trimmed faces where gears stack, dial
    rim 0.3 mm lower, teeth regenerated from the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
    [Infidex176V-IDENTIDEM.design-remix-counter-train.f3d, Infidex176V-IDENTIDEM.design-remix.3mf, Infidex176V-IDENTIDEM.design-remix.f3d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]
2026-09-24 feat(counter): larger frame markers and a two-colour counter face
    The frame markers grow from 0.5 x 0.8 mm to 0.9 x 1.7 mm, with 1.3 x 1.9 mm
    markers beside the numbers, and run out to the edge of the dial. Markers
    and numbers are now 0.4 mm deep, two layers, so they survive first-layer
    squish when the face prints dial-down.
    counter-face-two-colour.3mf adds a flush inlay part for a second filament.
    The face also carries the flat thumbscrew seat underside from Fusion v10.
    [Infidex176V-IDENTIDEM.design-remix.3mf, counter-face-two-colour.3mf, counter-face.3mf]
2026-09-24 feat(counter): refine the gear bay and locate the cover on the dial
    - idler 2 pin is a single 3.2 mm pin up to the gear top
    - idler 3 pin runs up to the gear top
    - cover reliefs over the sprocket pinion and idler 2 are 0.5 mm deep
    - a 25 mm boss on the body around the dial locates the cover in a
    25.2 mm recess
    - the STEP now includes the counter face inlay
    [Infidex176V-IDENTIDEM.design-remix.3mf, Infidex176V-IDENTIDEM.design-remix.f3d, Infidex176V-IDENTIDEM.design-remix.step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]
2026-09-24 fix(body): keep the idler 3 pin inside the body so body-top prints flat
    a5eedc9 ran the idler 3 pin up to 1.8 mm above the body's top face,
    the face body-top prints on, which left the part balanced on the pin tip.
    The pin now stops level with the top face as a 3.2 mm pin in a 3.6 mm
    idler 3 bore, and both bodies sit back on their full faces.
    [Infidex176V-IDENTIDEM.design-remix.3mf, Infidex176V-IDENTIDEM.design-remix.f3d, Infidex176V-IDENTIDEM.design-remix.step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]
2026-09-24 fix(counter): size idler 2's bore to its single-diameter pin
    Idler 2 kept a 4.0 mm lower bore from the old stepped pin, leaving 0.8 mm
    of clearance around the 3.2 mm pin that replaced it. The bore is now 3.6 mm
    for the full 4 mm height, the same 0.4 mm drawn clearance as the other
    idlers, so the pin locates the gear along its whole length.
    [Infidex176V-IDENTIDEM.design-remix.3mf, Infidex176V-IDENTIDEM.design-remix.f3d, Infidex176V-IDENTIDEM.design-remix.step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]
2026-09-24 fix(body): close the non-manifold edge under the chamber rear wall
    The chamber floor and the rear wall above it met only along a 72 mm line,
    where a 0.7 mm slot under the wall began level with the floor. That left
    one non-manifold edge in body-solid and body-bottom, carried since the
    first release. The slot had no opening anywhere, so it is now filled
    solid; nothing on the outside of either body changes, and both meshes
    are watertight.
    [Infidex176V-IDENTIDEM.design-remix.3mf, Infidex176V-IDENTIDEM.design-remix.f3d, Infidex176V-IDENTIDEM.design-remix.step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]
2026-09-24 feat(tools): parameterise counter-train face heights, stepped bores and tooth phase
    Replace the single face width, layer gap and base height with the
    underside and top of every toothed layer, give each bore a lower and
    upper diameter with a step height, and draw each wheel at the phase
    that meshes it with its pinion. Clash detection now also checks the
    axial gap between gears that pass over each other. The script cuts the
    bores after joining the layers and removes ct_* parameters left by
    older versions.
2026-09-24 chore(cad): rebuild the counter-train model with the fitted gears
    The idlers the generator now builds match the main model's
    counter-coupling-gear and counter-idler-1/2 to within 0.03 mm3, and the
    tooth zones of the sprocket pinion and dial wheel tool bodies match
    exactly.
    [Infidex176V-IDENTIDEM.design-remix-counter-train.f3d]
2026-09-24 docs: add a changelog with semantic versions for printed parts
    Each release lists its commits and the parts to reprint. Major means parts from the previous release no longer fit together, minor adds parts, variants or tools, and patch covers single-part fixes, re-exports and docs.
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2026-09-24 docs(readme): bring the build notes up to date with 2.0.0
    Add the counter gears to the fitting order, the cover's locating boss,
    the two-colour counter face as a part choice, the flocking templates in
    the file table and a pointer to the changelog's reprint lists. Correct
    the S1-S5 and S13 engagement and the thumbscrew recess to match the
    CAD, and show the counter face section.
2026-09-25 fix(counter): tighten cover, sprocket and ratchet-coupling-gear tolerances
    Printed parts showed gaps at these fits. The cover, sprocket and
    ratchet-coupling-gear are revised in the CAD with their outer dimensions
    unchanged, and re-exported to the print project and their part files.
    [Infidex176V-IDENTIDEM.design-remix.3mf, Infidex176V-IDENTIDEM.design-remix.f3d, Infidex176V-IDENTIDEM.design-remix.step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]
2026-09-26 fix(body): enlarged sprocket-coupling gear hole
    [Infidex176V-IDENTIDEM.design-remix.3mf, Infidex176V-IDENTIDEM.design-remix.f3d, Infidex176V-IDENTIDEM.design-remix.step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]
2026-09-27 fix(counter): tighten the idler bores to 0.2 mm over their pins
    The idlers ran loose on their pins. counter-coupling-gear goes from
    4.4/3.6 to 4.2/3.4, counter-idler-1 from 3.61 to 3.4 and counter-idler-2
    from 3.6 to 3.4, on Ø4.0/Ø3.2 pins. Step heights and outer dimensions are
    unchanged. The three part 3MFs and their meshes in the print project are
    re-exported from the CAD in their existing placement.
    The counter-train generator defaults and its as-built bore test follow
    the model, so the script still rebuilds the gears in the main model.
    The CAD also carries a work-in-progress cover-with-drag-arm-optional.
    Its arm sits inside the body's dial boss, so it is not exported or
    documented ye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
    [Infidex176V-IDENTIDEM.design-remix.3mf, Infidex176V-IDENTIDEM.design-remix.f3d, Infidex176V-IDENTIDEM.design-remix.step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]
2026-09-27 chore(cad): remove the work-in-progress drag-arm cover
    cover-with-drag-arm-optional clashed with the body's dial boss and was
    never exported or documented. Every other solid is unchanged.
    [Infidex176V-IDENTIDEM.design-remix.f3d, Infidex176V-IDENTIDEM.design-remix.step]
2026-09-27 chore(cad): rebuild the counter-train model with the 2.0.2 bores
    The parametric model still had the 2.0.1 idler bores, so it no longer
    matched the main model. Only the three bore radii change: 3.61 and 3.6
    to 3.4, and the stepped 4.4/3.6 to 4.2/3.4.
    Also ignore the .vscode/ folder Fusion creates when editing the script.
    [Infidex176V-IDENTIDEM.design-remix-counter-train.f3d]
2026-09-27 feat(counter): add the drag counter dial as an alternative
    drag-cover carries a tower beside the dial with a seventh D2x3 ball
    plunger (P7), and drag-counter-face has a 0.12 mm groove round its rim
    for the ball. The friction takes up the train's backlash so the dial
    stops in the same place and doesn't flutter. The tower is 0.2 mm clear
    of the rim and P7's hole matches P1-P6 at 2.2 mm.
    cover and counter-face become simple-cover and simple-counter-face so
    the two pairs read as a choice. Their geometry is unchanged. The drag
    parts are exported through the same transforms as their simple
    siblings and sit beside them on plates 7 and 8 of the project.
    [Infidex176V-IDENTIDEM.design-remix.3mf, Infidex176V-IDENTIDEM.design-remix.f3d, counter-face-two-colour.3mf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]
2026-09-27 docs(changelog): correct the 2.1.0 plate note
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2026-09-27 docs: fix insert sizes, idler names and plunger wording
    The insert section told builders to buy M3 x 4 when ten of the fourteen
    are M2. The idler numbers now name their part files, since
    counter-idler-1 is idler 2 and reads like idler 1. P7 goes in from the
    dial side, not from inside a bore. Also: a stale note about guide names,
    the drill size for idler 1's lower bore, three idlers not two, CAD Z
    heights labelled as such, and the drag pair described as an alternative
    rather than a replacement. The hardware guide PDF is rebuilt.
2026-09-27 build(tools): add rtree to the cad dependency group
    trimesh's closest-point queries, which the STEP-to-3MF fit uses for ICP
    and for the surface error, need an rtree index.
2026-09-27 feat(tools): read the STEP and the 3MFs and fit meshes onto each other
    Brings the throwaway export scripts into the repository as a package:
    named solids from the STEP and their meshes, mesh read and write in 3MF
    model XML with byte-for-byte zip rewrites, the Bambu project's objects,
    and a rigid fit that recovers how a part was flipped, spun and moved on
    the bed. The fit starts from the principal axes so parts tilted at any
    angle are found, and measures the error from mesh vertices to the STEP
    surface so coarse Fusion exports are not marked down for facet size.
    OCCT drops or garbles some Fusion cone faces; those solids are meshed
    again after a NURBS conversion.
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2026-09-27 feat(tools): re-export parts from the STEP, keeping their placement
    Fits the part's solid from the committed STEP onto each of its meshes
    and writes the new solid through the same transform, so a CAD change
    lands in the part file, any two-colour file and the project object
    without moving on the bed. Nothing is written unless every old fit is
    within tolerance, and the project's face counts follow the new mesh.
2026-09-27 feat(tools): check the counter gears for clearance in the assembled STEP
    The counter-train Fusion script cannot see the body walls or the covers.
    This reports shared volume and smallest gap for every gear against the
    body, top, both covers and the other gears, and fails on an overlap
    between parts that should not touch. Meshing pairs are reported only;
    their tooth clearance belongs to the gear maths. Each housing part is
    clipped to the gear's neighbourhood first, which takes the body checks
    from minutes to under a second.
2026-09-27 docs(tools): describe the CAD export and check tasks
    Says what verify, export and clearance do, the workflow after a CAD
    change, the name mapping and fit metric, and what is still manual.
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2026-09-28 feat(counter): add detent flutes to the drag counter face
    The drag face's backlash was taken up by P7's friction, but nothing
    settled it on a number. 25 vertical V-flutes, one under each frame
    marker, give the ball a seat at every frame: 120 deg included, apex at
    r 9.66, 0.22 mm below the groove floor, cut through the rim band Z
    47.4-48.9. The ball drops 0.10 mm and keeps 0.08 mm of preload. The
    120 deg flank keeps the detent's pull on the face well under S13's
    grip, so the face clicks rather than slipping on the hub.
    The flutes run along Z, so with the face printed dial-down they print
    as notches in the wall. The simple face and every other part are
    unchanged; verify passes 72 of 72 and cl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
    [Infidex176V-IDENTIDEM.design-remix.3mf, Infidex176V-IDENTIDEM.design-remix.f3d, drag-counter-face-two-colour.3mf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]
2026-09-28 feat(counter): firmer detents, matching dial markers and knob arrows
    The 120 deg flutes clicked but felt soft in a print test. The flutes are
    now 105 deg with the apex at r 9.58 (0.30 mm below the groove floor):
    the ball still drops 0.10 mm and keeps its preload, the face snaps in
    about a third more firmly, and the deeper notch survives the nozzle's
    rounding better.
    The drag cover's tower arrow gives way to the same triangle as the
    simple cover, and both triangles move from 102 to 108 deg about the
    dial axis. At 108 deg the marker is exactly five frames from P7, so
    the detent centres each number on it instead of pulling it 6 deg off.
    The advance and rewind knobs gain engraved arrows for th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
    [Infidex176V-IDENTIDEM.design-remix.3mf, Infidex176V-IDENTIDEM.design-remix.f3d, advance-knob.3mf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]
2026-09-28 docs: document the triangle marker, 105 deg flutes and knob arrows
    The drag cover's reading marker is now the same triangle as the simple
    cover's, five frames round from P7, so the README, the guide and
    Figure 11 no longer mention the tower arrow. Figure 11 is redrawn from
    the current STEP and shows the flutes and the 72 deg offset. The
    changelog records the firmer flutes, the knob arrows, and that a 2.1.0
    drag cover still works with the fluted face.
2026-09-28 build(docs): add a mise task that prints the hardware guide
    mise run test syncs the default dependency groups, which uninstalls
    Playwright, so the next guide build failed until someone reinstalled it
    and its browser by hand. mise run guide installs both, then prints the
    PDF.
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2026-09-28 fix(cad): make export safe to run twice
    A second export before committing fitted the old STEP solid onto a mesh that was
    already the new part, which drifted placement by a few microns while staying under
    tolerance. Each mesh is now also fitted with the new solid; when that fits better and
    within 1e-3 mm the mesh is reported as already exported and left alone.
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2026-09-28 feat(cad): add new STEP solids to the 3MFs placed like a sibling
    The 20-frame faces and idlers need part files and project objects. add writes the new
    solid through the transform that fits the sibling's solid onto each sibling mesh (part
    file, two-colour file with its inlay, project object cloned with the sibling's print
    settings), then puts the object at a free spot on the plate. It refuses before writing
    anything if a fit fails, the bed contact differs or the plate is full.
    verify now reads the inlay name from each two-colour file (a named solid such as
    counter-face-20-inlay, or the Body1.. bodies for counter-face-inlay), takes --parts and
    --project for checking a copy, and checks every p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
2026-09-28 feat(3mf): give each counter option its own plate
    Builders choose one cover, one idler set and one face; with the options sharing the
    small-parts plates they had to delete the ones they did not want. cad.layout makes a
    plate per option (simple and drag cover, 25-frame idlers, simple and drag 25 face with
    the 0.2 mm nozzle note) and moves the parts there; the shared counter gears stay on
    Small parts 2. With 14 plates Bambu Studio lays them out in 4 columns, so every object
    moved with its plate. The 20-frame plates are made by rerunning the layout after add
    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
    [Infidex176V-IDENTIDEM.design-remix.3mf]
2026-09-28 feat(cad): check alternative counter parts as options in clearance
    The -20 idlers will sit on the same axes as the 25-frame ones, and the simple and drag
    covers already overlap, so checking every part against every other would report clashes
    between parts that are never in one camera. clearance now knows the option sets (covers,
    idler sets, faces), checks each idler set in its own train with its own meshing pairs,
    checks each face against every cover and counter-gear, and skips options missing from
    the STEP with a note.
2026-09-28 docs(tools): describe add, plates, layout and the clearance option sets
    The CAD section still said new parts had to be imported by hand and that clearance
    checked every part against every other.
2026-09-28 fix(tools): move the 20-frame 14:28 mesh from idler 2 to idler 1
    A trial build in Fusion found that a 14-tooth pinion on idler 2 reaches
    r 4.94, past both covers' wall at r 4.61, so it would cut 0.33 mm into
    simple-cover and drag-cover. The gear maths can't see the covers.
    The same 40:1 ratio works on mesh 2, where idler 1's pinion has no
    cover or body wall nearby, so TWENTY_FRAME_TRAIN, the parameter hints
    and the README recipe now use ct_pinion1_teeth 14 and ct_wheel2_teeth
    28, and the README says to run clearance on any new train.
2026-09-28 refactor(cad): drop the 20-frame parts from layout and clearance
    The 20-frame counter is parked, so the tools should not name parts that do not exist.
    The layout covers the 25-frame options only; clearance keeps its option sets general
    (pairs() takes the sets, a new option is a new entry) with today's parts as defaults.
    Tests use made-up option names instead.
2026-09-29 chore(3mf): re-save the project in Bambu Studio for plate thumbnails
    The five counter plates added by the layout had no thumbnails and the
    two small-parts plates showed parts that had moved. Albert opened the
    project, checked all 14 plates and saved it. verify passes 86 of 86.
    [Infidex176V-IDENTIDEM.design-remix.3mf]
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2026-09-30 feat(counter): seat P7 in the flutes and drive the face through dog teeth
    A print of the 105 deg flutes had play at every frame. P7 pushes the
    face 0.14 mm across until its skirt meets the cover step, and the old
    budget assumed a centred face: the ball ran out of travel before it
    reached a flute, and it bridged the flute on its edges anyway.
    drag-cover: the tower face and P7's seat and hole move 0.14 mm towards
    the dial. drag-counter-face: the ball groove is gone and the flutes are
    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
    [Infidex176V-IDENTIDEM.design-remix.3mf, Infidex176V-IDENTIDEM.design-remix.f3d, counter-gear.3mf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]
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2026-09-30 docs(tools): say the dial wheel's hub, recess and dog teeth live in the main model
    The counter-train script builds only the dial wheel's tooth zone as a tool body. Swapping in new teeth must keep counter-gear's other features, or the faces lose their drive.
2026-09-30 feat(cad): drop the counter dog teeth and fit an ISO 518 cold shoe
    The dog teeth between counter-gear and the counter faces made no real
    difference to slop or play in use, and the friction-only fit is easier
    to reset. counter-gear and simple-counter-face are back to their
    2.1.0 shape, and drag-counter-face keeps the rev 2 detent without the
    notches.
    cold-shoe is replaced by a shoe drawn to ISO 518. It has the same
    footprint and the same two countersunk holes for S6-S7, so it fits
    the body as before.
    verify passes 86 of 86 and clearance finds no clashes.
    [Infidex176V-IDENTIDEM.design-remix.3mf, Infidex176V-IDENTIDEM.design-remix.f3d, cold-shoe.3mf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]
2026-09-30 docs: go back to the friction-only counter face
    The README and the guide describe the thumbscrew grip and reset again, and the drag option asks for S13 to be tightened firmly. Figure 8 is redrawn without the dog tooth.
2026-09-30 fix(cad): seat viewfinder-var-1 on the cold-shoe floor
    Its foot sat 0.032 mm into the shoe floor and 0.016 mm off-centre across the slot. It now sits exactly where viewfinder-var-2 does (moved +0.0363 X, -0.0137 Y, +0.0316 Z) and no longer overlaps the shoe. Only its place in the assembly changes, so the 3MFs are unchanged; verify passes 86 of 86.
    [Infidex176V-IDENTIDEM.design-remix.f3d]
2026-09-30 fix(tools): keep a part that only moved in the assembly on the bed
    export wrote the new solid through the old solid's fit. When the solid had only moved in the STEP, both fitted the mesh equally well, the 'already exported' check didn't fire, and the move was carried onto the bed: viewfinder-var-1 came out 0.036 mm below it. A part whose shape is unchanged is now placed by its own fit.
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2026-09-30 docs: correct five measurements against the STEP
    Drawing the figures from the STEP showed: the plunger holes are 3.1-3.2 mm deep in the body and 2.6 in the cover with a seat about 0.6 deep (not 3.1 and 0.57 for all); the M1-M2/M3 gap is 0.3 mm and M3 sits 0.2 below the spool head; the collar is Ø9.5 × Ø13.0; the open-door platen stands 1.6 mm proud.
2026-09-30 feat(cad): add arrow inlays and two-colour files for both knobs
    advance-knob-inlay and rewind-knob-inlay fill each knob's 1.0 mm arrow recess flush with its top face. add --inlay-for wrote advance-knob-two-colour.3mf and rewind-knob-two-colour.3mf in the counter 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
    [Infidex176V-IDENTIDEM.design-remix.f3d, advance-knob-two-colour.3mf, rewind-knob-two-colour.3mf]
2026-10-25 feat(cad): check the 20-frame idler set in clearance
    The 20-frame train changes idler 1 as well as idler 2, so the coupling
    gear can no longer be a fixed part. An idler set is now the three idlers
    of one train, coupling gear first, and two sets may share a part: the
    20-frame set is counter-coupling-gear-20, counter-idler-1-20 and the
    25-frame counter-idler-2. Until the -20 parts are in the STEP the set is
    skipped with a note, as before.
2026-10-25 feat(cad): read a two-colour inlay made of numbered pieces
    The 20-frame counter-face inlay is 27 separate glyphs, and Fusion exports
    each as its own body. An inlay called <name> can now also be the solids
    <name>-1, <name>-2, ... in the STEP: add and verify take them together,
    and verify no longer lists them as loose once a 3MF holds the inlay.
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
